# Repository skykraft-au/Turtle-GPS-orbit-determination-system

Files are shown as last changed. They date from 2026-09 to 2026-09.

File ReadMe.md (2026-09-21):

# Overview
The Turtle GPS is an open-source, cost-effective, low-power, and low-weight solution to orbit determination. The device resolves the issues faced by standard tracking methods such as radar while democratising space by making tracking cooperative and community-based. The device satisfies CoCom regulations by being post-processed and non-continuous; instead, it beacons GPS data over LoRa packets at specified intervals.

The device is highly configurable through the FPGA Verilog code; see the configuration section below for more information.

Further development on the device is needed; the community is welcome to contribute to this. Information on directions for this development can be found in the Todo section below.

## Note regarding Turtle GPS v2.0
Note that the Turtle GPS v2.0 does not work by default, as there are issues regarding the flash and power supply components on the board; these issues are resolved in version 2.1. If you wish to use version 2.0, you will need to resolve these issues. The key issues and solutions are as follows:
- There are missing pull-up resistors on pins 1, 3, and 7 of the Flash memory; these should be 10 kΩ.
- The pull-up resistors on the M0, M1, and M2 pins on the underside of the FPGA are 10 kΩ, but they should be 1 kΩ to initiate the correct startup configuration.
- A few issues exist in the lower half of the power supply, including incorrect placement of the boost converter, sensitive output of the first 3.3 V LDO, and insufficient current rating in both the diode and boost converter. To resolve this, I recommend bypassing this section by powering the board with 3.3 V through test point 3.
- The done indicator pin from the FPGA should be a pull-up and not a pull-down.

# Todo
- GPS v2.1: Resolve issues with v2.0, update FPGA clock to an LVCMOS TCXO, tune LoRa RF path to between 401 MHz and 403 MHz.
- Update code to default the LoRa frequency to 401 MHz to 403 MHz and cascade the FIR to allow for a sharper cutoff to be attained with the limited FPGA resources.
- Program LoRa receiving capabilities into the FPGA to allow for remote shutdown with a unique user-defined code.
- Optimise size, weight, and performance of the device
- Test in orbit
- Set up a public website for uploading and processing of data
- Add satellite ID code generator and logger to the website

# Configuration of the Device
By default, the packets transmitted over LoRa are 512 bits wide and include a unique, user-defined satellite ID Code, packet index, user-defined bits, and the actual data.
| Number of Bits | Bit Locations | Purpose |
| --- | --- | --- |
| 24 | \[512:489\] | Satellite ID Code |
| 12 | \[488:477\] | Packet Index |
| 28 | \[476:449\] | User-defined bits |
| 448 | \[448:0\] | GPS IQ Data |

The user-defined bits can be configured by changing the value of the respective register in the Verilog code. The configuration of the MAX2771 GNSS Receiver and the LoRa SX1276 can be changed by adjusting the values of their respective configuration registers in the MAX_Driver and LORA_Driver Verilog modules, respectively.

The total transmission size, as well as the sample size and whether samples are continuous or not, can all be configured through the value of the GPS_Config register in the GPS_Top Verilog module. Comments are included in the code to assist users with this.

# Licensing

This repository contains material under multiple licenses.

## Hardware

The hardware design files are licensed under CERN-OHL-P v2.

This includes:
- GPS v2.0/KiCad PCB/

## HDL and Software

The HDL and software source code are licensed under the MIT License.

This includes:
- GPS v2.0/Software and HDL/

## Documentation

Documentation, diagrams, and images are licensed under
Creative Commons Attribution 4.0 International (CC BY 4.0).

This includes:
- GPS v2.0/BoM/

A copy of each license is available in the licenses/ directory.

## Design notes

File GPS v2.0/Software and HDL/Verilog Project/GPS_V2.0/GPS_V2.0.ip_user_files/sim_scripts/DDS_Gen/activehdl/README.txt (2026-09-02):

################################################################################
# Vivado (TM) v2024.1 (64-bit)
#
# README.txt: Please read the sections below to understand the steps required to
#             run the exported script and how to fetch design source file details
#             from the file_info.txt file.
#
# Generated by export_simulation on Mon Aug 10 12:43:21 +1000 2026
#
################################################################################

1. Steps to run the generated simulation script

From the shell prompt in the current directory, issue the following command:-

./DDS_Gen.sh

This command will launch the 'compile', 'elaborate' and 'simulate' functions
implemented in the script file for the 3-step flow. These functions are called
from the main 'run' function in the script file.

The 'run' function first calls the 'check_args' function, the purpose of which
is to verify the generated script arguments and print error if incorrect switch
is specified. The 'run' function then calls the 'setup' function, the purpose of
which is to specify custom or initialization commands. The function also executes
following sub-functions:-
'reset_run' if -reset_run switch is specified.
'reset_log' if -reset_log switch is specified.

The purpose of 'reset_run' function' is to delete the simulator generated design
data from the previous run and the purpose of 'reset_log' function' is to delete
the simulator generated log files.

The 'run' function then calls the 'init_lib' function, the purpose of which is to
create design library mappings and directories. This function is called before the
'compile' step. By default, if '-step' switch is specified with the script then the
script will execute that specfic step, else it will execute all steps applicable
for the target simulator.

For more information on the script, please type './DDS_Gen.sh -help'

2. Design source file information

export_simulation generates a 'file_info.txt' file that contains design file information
based on the compile order when export_simulation was executed from Vivado. The file
contains information about the file name, type, library it is compiled into, whether
it is part of the IP, associated library, file path information in a comma separated
format. This file can be parsed to extract the required information for generating a
custom script or can be read from verification test infra.

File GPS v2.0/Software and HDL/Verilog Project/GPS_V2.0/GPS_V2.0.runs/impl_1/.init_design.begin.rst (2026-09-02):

<?xml version="1.0"?>
<ProcessHandle Version="1" Minor="0">
    <Process Command=".planAhead." Owner="DinoColling" Host="WINSKYK-PR7FMTG" Pid="47460">
    </Process>
</ProcessHandle>

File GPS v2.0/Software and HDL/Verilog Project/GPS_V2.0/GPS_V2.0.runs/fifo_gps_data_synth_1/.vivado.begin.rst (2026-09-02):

<?xml version="1.0"?>
<ProcessHandle Version="1" Minor="0">
    <Process Command="vivado.bat" Owner="DinoColling" Host="WINSKYK-PR7FMTG" Pid="12496" HostCore="18" HostMemory="016568107008">
    </Process>
</ProcessHandle>

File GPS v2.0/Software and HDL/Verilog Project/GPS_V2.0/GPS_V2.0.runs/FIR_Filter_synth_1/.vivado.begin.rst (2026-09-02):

<?xml version="1.0"?>
<ProcessHandle Version="1" Minor="0">
    <Process Command="vivado.bat" Owner="DinoColling" Host="WINSKYK-PR7FMTG" Pid="38172" HostCore="18" HostMemory="016568107008">
    </Process>
</ProcessHandle>

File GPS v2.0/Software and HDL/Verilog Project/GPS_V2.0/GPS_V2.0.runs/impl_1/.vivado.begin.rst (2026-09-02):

<?xml version="1.0"?>
<ProcessHandle Version="1" Minor="0">
    <Process Command="vivado.bat" Owner="DinoColling" Host="WINSKYK-PR7FMTG" Pid="2948" HostCore="18" HostMemory="016568107008">
    </Process>
</ProcessHandle>
<?xml version="1.0"?>
<ProcessHandle Version="1" Minor="0">
    <Process Command="vivado.bat" Owner="DinoColling" Host="WINSKYK-PR7FMTG" Pid="38740" HostCore="18" HostMemory="016568107008">
    </Process>
</ProcessHandle>
<?xml version="1.0"?>
<ProcessHandle Version="1" Minor="0">
    <Process Command="vivado.bat" Owner="DinoColling" Host="WINSKYK-PR7FMTG" Pid="39036" HostCore="18" HostMemory="016568107008">
    </Process>
</ProcessHandle>
<?xml version="1.0"?>
<ProcessHandle Version="1" Minor="0">
    <Process Command="vivado.bat" Owner="DinoColling" Host="WINSKYK-PR7FMTG" Pid="36636" HostCore="18" HostMemory="016568107008">
    </Process>
</ProcessHandle>
<?xml version="1.0"?>
<ProcessHandle Version="1" Minor="0">
    <Process Command="vivado.bat" Owner="DinoColling" Host="WINSKYK-PR7FMTG" Pid="20428" HostCore="18" HostMemory="016568107008">
    </Process>
</ProcessHandle>
<?xml version="1.0"?>
<ProcessHandle Version="1" Minor="0">
    <Process Command="vivado.bat" Owner="DinoColling" Host="WINSKYK-PR7FMTG" Pid="31564" HostCore="18" HostMemory="016568107008">
    </Process>
</ProcessHandle>
<?xml version="1.0"?>
<ProcessHandle Version="1" Minor="0">
    <Process Command="vivado.bat" Owner="DinoColling" Host="WINSKYK-PR7FMTG" Pid="3468" HostCore="18" HostMemory="016568107008">
    </Process>
</ProcessHandle>
<?xml version="1.0"?>
<ProcessHandle Version="1" Minor="0">
    <Process Command="vivado.bat" Owner="DinoColling" Host="WINSKYK-PR7FMTG" Pid="37884" HostCore="18" HostMemory="016568107008">
    </Process>
</ProcessHandle>
<?xml version="1.0"?>
<ProcessHandle Version="1" Minor="0">
    <Process Command="vivado.bat" Owner="DinoColling" Host="WINSKYK-PR7FMTG" Pid="37788" HostCore="18" HostMemory="016568107008">
    </Process>
</ProcessHandle>
<?xml version="1.0"?>
<ProcessHandle Version="1" Minor="0">
    <Process Command="vivado.bat" Owner="DinoColling" Host="WINSKYK-PR7FMTG" Pid="22512" HostCore="18" HostMemory="016568107008">
    </Process>
</ProcessHandle>
<?xml version="1.0"?>
<ProcessHandle Version="1" Minor="0">
    <Process Command="vivado.bat" Owner="DinoColling" Host="WINSKYK-PR7FMTG" Pid="41432" HostCore="18" HostMemory="016568107008">
    </Process>
</ProcessHandle>
<?xml version="1.0"?>
<ProcessHandle Version="1" Minor="0">
    <Process Command="vivado.bat" Owner="DinoColling" Host="WINSKYK-PR7FMTG" Pid="43732" HostCore="18" HostMemory="016568107008">
    </Process>
</ProcessHandle>
<?xml version="1.0"?>
<ProcessHandle Version="1" Minor="0">
    <Process Command="vivado.bat" Owner="DinoColling" Host="WINSKYK-PR7FMTG" Pid="5312" HostCore="18" HostMemory="016568107008">
    </Process>
</ProcessHandle>
<?xml version="1.0"?>
<ProcessHandle Version="1" Minor="0">
    <Process Command="vivado.bat" Owner="DinoColling" Host="WINSKYK-PR7FMTG" Pid="44792" HostCore="18" HostMemory="016568107008">
    </Process>
</ProcessHandle>
<?xml version="1.0"?>
<ProcessHandle Version="1" Minor="0">
    <Process Command="vivado.bat" Owner="DinoColling" Host="WINSKYK-PR7FMTG" Pid="45352" HostCore="18" HostMemory="016568107008">
    </Process>
</ProcessHandle>

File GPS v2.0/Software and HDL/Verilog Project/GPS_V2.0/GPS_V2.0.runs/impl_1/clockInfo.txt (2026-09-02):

-------------------------------------
| Tool Version : Vivado v.2024.1
| Date         : Mon Aug 24 15:19:51 2026
| Host         : WINSKYK-PR7FMTG
| Design       : design_1
| Device       : xc7s15-ftgb196-1--
-------------------------------------

For more information on clockInfo.txt clock routing debug file see https://support.xilinx.com/s/article/000035660?language=en_US

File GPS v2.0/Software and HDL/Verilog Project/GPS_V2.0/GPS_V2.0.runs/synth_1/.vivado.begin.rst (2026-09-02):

<?xml version="1.0"?>
<ProcessHandle Version="1" Minor="0">
    <Process Command="vivado.bat" Owner="DinoColling" Host="WINSKYK-PR7FMTG" Pid="12692" HostCore="18" HostMemory="016568107008">
    </Process>
</ProcessHandle>

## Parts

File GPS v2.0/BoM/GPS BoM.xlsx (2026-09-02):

Part Name | Description | Quantity | Price per Unit (AUD) (10+) | Total Price (AUD) | Link for Purchase
GRM155R60J106ME05D | 10uF Ceramic Capacitor 0402 6.3v | 8 | 0.031 | 0.248 | GRM155R60J106ME05D Murata Electronics | Ceramic Capacitors | DigiKey (https://www.digikey.com/en/products/detail/murata-electronics/GRM155R60J106ME05D/11500166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) | GRM155R60J106ME05D &10uF Ceramic Capacitor 0402 6.3v &8 &0.248 \\
GRM155R61A475MEAAD | 4.7uF Ceramic Capacitor 0402 10v | 1 | 0.092 | 0.092 | GRM155R61A475MEAAD Murata Electronics | Ceramic Capacitors | DigiKey (https://www.digikey.com.au/en/products/detail/murata-electronics/GRM155R61A475MEAAD/6234735) | GRM155R61A475MEAAD &4.7uF Ceramic Capacitor 0402 10v &1 &0.092 \\
GRM155R71H471KA01D | 470pF Ceramic Capacitor 0402 50v | 2 | 0.054 | 0.108 | GRM155R71H471KA01D Murata Electronics | Ceramic Capacitors | DigiKey (https://www.digikey.com.au/en/products/detail/murata-electronics/GRM155R71H471KA01D/587231) | GRM155R71H471KA01D &470pF Ceramic Capacitor 0402 50v &2 &0.108 \\
GRM155R71C103KA01D | 10nF Ceramic Capacitor 0402 16v | 2 | 0.031 | 0.062 | GRM155R71C103KA01D Murata Electronics | Ceramic Capacitors | DigiKey (https://www.digikey.com.au/en/products/detail/murata-electronics/GRM155R71C103KA01D/587215) | GRM155R71C103KA01D &10nF Ceramic Capacitor 0402 16v &2 &0.062 \\
GJM1555C1H1R7BB01D | 1.7pF Ceramic Capacitor 0402 50v | 1 | 0.074 | 0.074 | GJM1555C1H1R7BB01D Murata Electronics | Ceramic Capacitors | DigiKey (https://www.digikey.com.au/en/products/detail/murata-electronics/GJM1555C1H1R7BB01D/2592897) | GJM1555C1H1R7BB01D &1.7pF Ceramic Capacitor 0402 50v &1 &0.074 \\
GJM1555C1H1R1CB01D | 1.1pF Ceramic Capacitor 0402 50v | 1 | 0.052 | 0.052 | GJM1555C1H1R1CB01D Murata Electronics | Ceramic Capacitors | DigiKey (https://www.digikey.com.au/en/products/detail/murata-electronics/GJM1555C1H1R1CB01D/702277) | GJM1555C1H1R1CB01D &1.1pF Ceramic Capacitor 0402 50v &1 &0.052 \\
GRM033R60J104KE19D | 100nF Ceramic Capacitor 0201 6.3v | 27 | 0.019 | 0.513 | GRM033R60J104KE19D Murata Electronics | Ceramic Capacitors | DigiKey (https://www.digikey.com.au/en/products/detail/murata-electronics/GRM033R60J104KE19D/702433) | GRM033R60J104KE19D &100nF Ceramic Capacitor 0201 6.3v &27 &0.513 \\
GRM155R61E105KA12D | 1uF Ceramic Capacitor 0402 25v | 12 | 0.042 | 0.504 | GRM155R61E105KA12D Murata Electronics | Ceramic Capacitors | DigiKey (https://www.digikey.com.au/en/products/detail/murata-electronics/GRM155R61E105KA12D/4905139) | GRM155R61E105KA12D &1uF Ceramic Capacitor 0402 25v &12 &0.504 \\
GRM155R60J474KE19D | 0.47uF Ceramic Capacitor 0402 6.3v | 6 | 0.074 | 0.444 | GRM155R60J474KE19D Murata Electronics | Ceramic Capacitors | DigiKey (https://www.digikey.com.au/en/products/detail/murata-electronics/GRM155R60J474KE19D/702530) | GRM155R60J474KE19D &0.47uF Ceramic Capacitor 0402 6.3v &6 &0.444 \\
GCM155R71H104KE02J | 100nF Ceramic Capacitor 0402 50v | 13 | 0.05 | 0.65 | GCM155R71H104KE02J Murata Electronics | Ceramic Capacitors | DigiKey (https://www.digikey.com.au/en/products/detail/murata-electronics/GCM155R71H104KE02J/4903705) | GCM155R71H104KE02J &100nF Ceramic Capacitor 0402 50v &13 &0.65 \\
GQM1875C2E150FB12D | 15pF Ceramic Capacitor 0603 250v | 1 | 0.48 | 0.48 | GQM1875C2E150FB12D Murata Electronics | Ceramic Capacitors | DigiKey (https://www.digikey.com.au/en/products/detail/murata-electronics/GQM1875C2E150FB12D/4419970) | GQM1875C2E150FB12D &15pF Ceramic Capacitor 0603 250v &1 &0.48 \\
GCM1555C1H101JA16D | 100pF Ceramic Capacitor 0402 50v | 4 | 0.047 | 0.188 | GCM1555C1H101JA16D Murata Electronics | Ceramic Capacitors | DigiKey (https://www.digikey.com.au/en/products/detail/murata-electronics/GCM1555C1H101JA16D/4903548) | GCM1555C1H101JA16D &100pF Ceramic Capacitor 0402 50v &4 &0.188 \\
GCM1555C1H751JA16D | 750pF Ceramic Capacitor 0402 50v | 1 | 0.052 | 0.052 | GCM1555C1H751JA16D Murata Electronics | Ceramic Capacitors | DigiKey (https://www.digikey.com.au/en/products/detail/murata-electronics/GCM1555C1H751JA16D/10700551) | GCM1555C1H751JA16D &750pF Ceramic Capacitor 0402 50v &1 &0.052 \\
GRM1555C1H470JA01D | 47pF Ceramic Capacitor 0402 50v | 5 | 0.035 | 0.175 | GRM1555C1H470JA01D Murata Electronics | Ceramic Capacitors | DigiKey (https://www.digikey.com.au/en/products/detail/murata-electronics/GRM1555C1H470JA01D/3693853) | GRM1555C1H470JA01D &47pF Ceramic Capacitor 0402 50v &5 &0.175 \\
GRM155R71E473KA88D | 47nF Ceramic Capacitor 0402 25v | 3 | 0.032 | 0.096 | GRM155R71E473KA88D Murata Electronics | Ceramic Capacitors | DigiKey (https://www.digikey.com.au/en/products/detail/murata-electronics/GRM155R71E473KA88D/702519) | GRM155R71E473KA88D &47nF Ceramic Capacitor 0402 25v &3 &0.096 \\
GJM1555C1H5R6BB01D | 5.6pF Ceramic Capacitor 0402 50v | 1 | 0.074 | 0.074 | GJM1555C1H5R6BB01D Murata Electronics | Ceramic Capacitors | DigiKey (https://www.digikey.com.au/en/products/detail/murata-electronics/GJM1555C1H5R6BB01D/2593043) | GJM1555C1H5R6BB01D &5.6pF Ceramic Capacitor 0402 50v &1 &0.074 \\
GRM1555C1H4R7CA01D | 4.7pF Ceramic Capacitor 0402 50v | 1 | 0.032 | 0.032 | GRM1555C1H4R7CA01D Murata Electronics | Ceramic Capacitors | DigiKey (https://www.digikey.com.au/en/products/detail/murata-electronics/GRM1555C1H4R7CA01D/3175193) | GRM1555C1H4R7CA01D &4.7pF Ceramic Capacitor 0402 50v &1 &0.032 \\
GRM1555C1H120FA01D | 12pF Ceramic Capacitor 0402 50v | 1 | 0.073 | 0.073 | GRM1555C1H120FA01D Murata Electronics | Ceramic Capacitors | DigiKey (https://www.digikey.com.au/en/products/detail/murata-electronics/GRM1555C1H120FA01D/3693922) | GRM1555C1H120FA01D &12pF Ceramic Capacitor 0402 50v &1 &0.073 \\
GRM1555C1H8R2CA01D | 8.2pF Ceramic Capacitor 0402 50v | 1 | 0.032 | 0.032 | GRM1555C1H8R2CA01D Murata Electronics | Ceramic Capacitors | DigiKey (https://www.digikey.com.au/en/products/detail/murata-electronics/GRM1555C1H8R2CA01D/3693886) | GRM1555C1H8R2CA01D &8.2pF Ceramic Capacitor 0402 50v &1 &0.032 \\
GRM1555C1H102JA01D | 1nF Ceramic Capacitor 0402 50v | 2 | 0.05 | 0.1 | GRM1555C1H102JA01D Murata Electronics | Ceramic Capacitors | DigiKey (https://www.digikey.com.au/en/products/detail/murata-electronics/GRM1555C1H102JA01D/702509) | GRM1555C1H102JA01D &1nF Ceramic Capacitor 0402 50v &2 &0.1 \\
GJM1555C1H6R8WB01D | 6.8pF Ceramic Capacitor 0402 50v | 2 | 0.134 | 0.268 | GJM1555C1H6R8WB01D Murata Electronics | Ceramic Capacitors | DigiKey (https://www.digikey.com.au/en/products/detail/murata-electronics/GJM1555C1H6R8WB01D/6606076) | GJM1555C1H6R8WB01D &6.8pF Ceramic Capacitor 0402 50v &2 &0.268 \\
GRM32ER60G337ME05L | 330uF Ceramic Capacitor 1210 4v | 1 | 1.695 | 1.695 | GRM32ER60G337ME05L Murata Electronics | Ceramic Capacitors | DigiKey (https://www.digikey.com.au/en/products/detail/murata-electronics/GRM32ER60G337ME05L/6155746) | GRM32ER60G337ME05L &330uF Ceramic Capacitor 1210 4v &1 &1.695 \\
GRM31CR61A476ME15L | 47uF Ceramic Capacitor 1206 10v | 1 | 0.32 | 0.32 | GRM31CR61A476ME15L Murata Electronics | Ceramic Capacitors | DigiKey (https://www.digikey.com.au/en/products/detail/murata-electronics/GRM31CR61A476ME15L/2334879) | GRM31CR61A476ME15L &47uF Ceramic Capacitor 1206 10v &1 &0.32 \\
GRM1555C1H100FA01D | 10pF Ceramic Capacitor 0402 50v | 1 | 0.064 | 0.064 | GRM1555C1H100FA01D Murata Electronics | Ceramic Capacitors | DigiKey (https://www.digikey.com.au/en/products/detail/murata-electronics/GRM1555C1H100FA01D/2543854) | GRM1555C1H100FA01D &10pF Ceramic Capacitor 0402 50v &1 &0.064 \\
1210YD107MAT4A | 100uF Ceramic Capacitor 1210 16v | 8 | 2.321 | 18.568 | 1210YD107MAT4A KYOCERA AVX | Ceramic Capacitors | DigiKey (https://www.digikey.com.au/en/products/detail/kyocera-avx/1210YD107MAT4A/11211375) | 1210YD107MAT4A &100uF Ceramic Capacitor 1210 16v &8 &18.568 \\
LQW15AN5N6C10D | 5.6nH Inductor 0402 | 1 | 0.154 | 0.154 | LQW15AN5N6C10D Murata Electronics | Fixed Inductors | DigiKey (https://www.digikey.com.au/en/products/detail/murata-electronics/LQW15AN5N6C10D/2594938) | LQW15AN5N6C10D &5.6nH Inductor 0402 &1 &0.154 \\
LQW15AN8N4G8ZD | 8.4nH Inductor 0402 | 1 | 0.201 | 0.201 | LQW15AN8N4G8ZD Murata Electronics | Fixed Inductors | DigiKey (https://www.digikey.com.au/en/products/detail/murata-electronics/LQW15AN8N4G8ZD/6799020) | LQW15AN8N4G8ZD &8.4nH Inductor 0402 &1 &0.201 \\
LBR2012T220K | 22uH Inductor 0805 | 1 | 0.114 | 0.114 | LBR2012T220K Taiyo Yuden | Fixed Inductors | DigiKey (https://www.digikey.com.au/en/products/detail/taiyo-yuden/LBR2012T220K/1788938) | LBR2012T220K &22uH Inductor 0805 &1 &0.114 \\
LQW15AN56NJ00D | 56nH Inductor 0402 | 1 | 0.128 | 0.128 | LQW15AN56NJ00D Murata Electronics | Fixed Inductors | DigiKey (https://www.digikey.com.au/en/products/detail/murata-electronics/LQW15AN56NJ00D/584364) | LQW15AN56NJ00D &56nH Inductor 0402 &1 &0.128 \\
LQW15AN30NJ00D | 30nH Inductor 0402 | 1 | 0.16 | 0.16 | LQW15AN30NJ00D Murata Electronics | Fixed Inductors | DigiKey (https://www.digikey.com.au/en/products/detail/murata-electronics/LQW15AN30NJ00D/2594896) | LQW15AN30NJ00D &30nH Inductor 0402 &1 &0.16 \\
LQW15AN8N2J00D | 8.2nH Inductor 0402 | 1 | 0.128 | 0.128 | LQW15AN8N2J00D Murata Electronics | Fixed Inductors | DigiKey (https://www.digikey.com.au/en/products/detail/murata-electronics/LQW15AN8N2J00D/584353) | LQW15AN8N2J00D &8.2nH Inductor 0402 &1 &0.128 \\
LQW15AN18NG00D | 18nH Inductor 0402 | 1 | 0.14 | 0.14 | LQW15AN18NG00D Murata Electronics | Fixed Inductors | DigiKey (https://www.digikey.com.au/en/products/detail/murata-electronics/LQW15AN18NG00D/2594860) | LQW15AN18NG00D &18nH Inductor 0402 &1 &0.14 \\
LQW15AN20NJ00D | 20nH Inductor 0402 | 1 | 0.128 | 0.128 | LQW15AN20NJ00D Murata Electronics | Fixed Inductors | DigiKey (https://www.digikey.com.au/en/products/detail/murata-electronics/LQW15AN20NJ00D/2594871) | LQW15AN20NJ00D &20nH Inductor 0402 &1 &0.128 \\
RC0402FR-0720KL | 20kOhm Resistor 0402 | 1 | 0.031 | 0.031 | RC0402FR-0720KL YAGEO | Chip Resistor - Surface Mount | DigiKey (https://www.digikey.com.au/en/products/detail/yageo/RC0402FR-0720KL/726557) | RC0402FR-0720KL &20kOhm Resistor 0402 &1 &0.031 \\
RC0402FR-07220KL | 220kOhm Resistor 0402 | 1 | 0.031 | 0.031 | RC0402FR-07220KL YAGEO | Chip Resistor - Surface Mount | DigiKey (https://www.digikey.com.au/en/products/detail/yageo/RC0402FR-07220KL/726564) | RC0402FR-07220KL &220kOhm Resistor 0402 &1 &0.031 \\
RC0402FR-07100KL | 100kOhm Resistor 0402 | 4 | 0.031 | 0.124 | RC0402FR-07100KL YAGEO | Chip Resistor - Surface Mount | DigiKey (https://www.digikey.com.au/en/products/detail/yageo/RC0402FR-07100KL/726526) | RC0402FR-07100KL &100kOhm Resistor 0402 &4 &0.124 \\
RC0603FR-0710KL | 10kOhm Resistor 0402 | 16 | 0.036 | 0.576 | RC0603FR-0710KL YAGEO | Chip Resistor - Surface Mount | DigiKey (https://www.digikey.com.au/en/products/detail/yageo/RC0603FR-0710KL/726880) | RC0603FR-0710KL &10kOhm Resistor 0402 &16 &0.576 \\
RC0402JR-0733RL | 33Ohm Resistor 0402 | 25 | 0.028 | 0.7 | RC0402JR-0733RL YAGEO | Chip Resistor - Surface Mount | DigiKey (https://www.digikey.com.au/en/products/detail/yageo/RC0402JR-0733RL/726467) | RC0402JR-0733RL &33Ohm Resistor 0402 &25 &0.7 \\
RC0603FR-07330RL | 330Ohm Resistor 0402 | 3 | 0.036 | 0.108 | RC0603FR-07330RL YAGEO | Chip Resistor - Surface Mount | DigiKey (https://www.digikey.com.au/en/products/detail/yageo/RC0603FR-07330RL/727162) | RC0603FR-07330RL &330Ohm Resistor 0402 &3 &0.108 \\
RT0402BRD0715KL | 15kOhm Resistor 0402 | 1 | 0.114 | 0.114 | RT0402BRD0715KL YAGEO | Chip Resistor - Surface Mount | DigiKey (https://www.digikey.com.au/en/products/detail/yageo/RT0402BRD0715KL/1069050) | RT0402BRD0715KL &15kOhm Resistor 0402 &1 &0.114 \\
RC0402JR-070RL | 0Ohm Resistor 0402 | 2 | 0.015 | 0.03 | RC0402JR-070RL YAGEO | Chip Resistor - Surface Mount | DigiKey (https://www.digikey.com.au/en/products/detail/yageo/RC0402JR-070RL/726406) | RC0402JR-070RL &0Ohm Resistor 0402 &2 &0.03 \\
BZT52C20-7-F | 20v Zener Diode | 1 | 0.175 | 0.175 | BZT52C20-7-F Diodes Incorporated | Single Zener Diodes | DigiKey (https://www.digikey.com.au/en/products/detail/diodes-incorporated/bzt52c20-7-f/755470) | BZT52C20-7-F &20v Zener Diode &1 &0.175 \\
SML-D12U1WT86 | Red LED 0603 | 3 | 0.122 | 0.366 | SML-D12U1WT86 Rohm Semiconductor | LED Indication - Discrete | DigiKey (https://www.digikey.com.au/en/products/detail/rohm-semiconductor/sml-d12u1wt86/5843853) | SML-D12U1WT86 &Red LED 0603 &3 &0.366 \\
MT25QL128ABA1ESE-0SIT TR | Flash Memory 128Mbit | 1 | 11.521 | 11.521 | MT25QL128ABA1ESE-0SIT TR Micron Technology Inc. | Memory | DigiKey (https://www.digikey.com.au/en/products/detail/micron-technology-inc/mt25ql128aba1ese-0sit-tr/6595661) | MT25QL128ABA1ESE-0SIT TR &Flash Memory 128Mbit &1 &11.521 \\
M20-9990246 | 2 pin Connector | 1 | 0.115 | 0.115 | M20-9990246 Harwin Inc. | Headers, Male Pins | DigiKey (https://www.digikey.com.au/en/products/detail/harwin-inc/M20-9990246/3728226) | M20-9990246 &2 pin Connector &1 &0.115 \\
MMCX-J-P-H-ST-SM1 | MMCX Connector | 3 | 3.5526 | 10.6578 | MMCX-J-P-H-ST-SM1 Samtec Inc. | Coaxial Connector (RF) Assemblies | DigiKey (https://www.digikey.com.au/en/products/detail/samtec-inc/mmcx-j-p-h-st-sm1/2707983) | MMCX-J-P-H-ST-SM1 &MMCX Connector &3 &10.6578 \\
878311420 | JTAG Connector | 1 | 2.77594 | 2.77594 | 0878311420 Molex | Headers, Male Pins | DigiKey (https://www.digikey.com.au/en/products/detail/molex/0878311420/662449) | 878311420 &JTAG Connector &1 &2.77594 \\
DMP1045UQ-7 | P-Channel MOSFET | 1 | 0.47 | 0.47 | DMP1045UQ-7 Diodes Incorporated | Single FETs, MOSFETs | DigiKey (https://www.digikey.com.au/en/products/detail/diodes-incorporated/dmp1045uq-7/8537809) | DMP1045UQ-7 &P-Channel MOSFET &1 &0.47 \\
PTS647SK38SMTR2 LFS | Tactile SPST Switch | 1 | 0.374 | 0.374 | PTS647SK38SMTR2 LFS C&K | Tactile Switches | DigiKey (https://www.digikey.com.au/en/products/detail/c-k/pts647sk38smtr2-lfs/9649862) | PTS647SK38SMTR2 LFS &Tactile SPST Switch &1 &0.374 \\
ECS-TXO-2520MV-320-AN-TR | 32MHz TCXO CMOS | 1 | 2.628 | 2.628 | ECS-TXO-2520MV-320-AN-TR ECS Inc. | Oscillators | DigiKey (https://www.digikey.com.au/en/products/detail/ecs-inc/ecs-txo-2520mv-320-an-tr/13178996) | ECS-TXO-2520MV-320-AN-TR &32MHz TCXO CMOS &1 &2.628 \\
ADP160AUJZ-1.8-R7 | 1.8v LDO | 1 | 1.581 | 1.581 | ADP160AUJZ-1.8-R7 Analog Devices Inc. | Voltage Regulators - Linear, Low Drop Out (LDO) Regulators | DigiKey (https://www.digikey.com.au/en/products/detail/analog-devices-inc/adp160aujz-1-8-r7/2510619) | ADP160AUJZ-1.8-R7 &1.8v LDO &1 &1.581 \\
MAX8570ELT+T | Boost Converter | 1 | 5.772 | 5.772 | MAX8570ELT+T Analog Devices Inc./Maxim Integrated | Special Purpose Regulators | DigiKey (https://www.digikey.com.au/en/products/detail/analog-devices-inc-maxim-integrated/max8570elt-t/2658803) | MAX8570ELT+T &Boost Converter &1 &5.772 \\
LP5912-1.0DRVR | 1.0v LDO | 1 | 1.393 | 1.393 | LP5912-1.0DRVR Texas Instruments | Voltage Regulators - Linear, Low Drop Out (LDO) Regulators | DigiKey (https://www.digikey.com.au/en/products/detail/texas-instruments/LP5912-1-0DRVR/9860178) | LP5912-1.0DRVR &1.0v LDO &1 &1.393 \\
NCV4274CST33T3G | 3.3v LDO large-range | 1 | 1.197 | 1.197 | NCV4274CST33T3G onsemi | Voltage Regulators - Linear, Low Drop Out (LDO) Regulators | DigiKey (https://www.digikey.com.au/en/products/detail/onsemi/ncv4274cst33t3g/7562181) | NCV4274CST33T3G &3.3v LDO large-range &1 &1.197 \\
TLV73333PDBVR | 3.3v LDO Precise | 1 | 0.172 | 0.172 | TLV73333PDBVR Texas Instruments | Voltage Regulators - Linear, Low Drop Out (LDO) Regulators | DigiKey (https://www.digikey.com.au/en/products/detail/texas-instruments/tlv73333pdbvr/5022378) | TLV73333PDBVR &3.3v LDO Precise &1 &0.172 \\
MAX2771ETI+T | RF GNSS Receiver | 1 | 12.87104 | 12.87104 | MAX2771ETI+T Analog Devices Inc./Maxim Integrated | RF Receivers | DigiKey (https://www.digikey.com.au/en/products/detail/analog-devices-inc-maxim-integrated/max2771eti-t/9833527) | MAX2771ETI+T &RF GNSS Receiver &1 &12.87104 \\
XC7S15-1FTGB196C | Spartan-7 FPGA | 1 | 38.9 | 38.9 | XC7S15-1FTGB196C AMD | FPGAs (Field Programmable Gate Array) | DigiKey (https://www.digikey.com.au/en/products/detail/amd/xc7s15-1ftgb196c/9380262) | XC7S15-1FTGB196C &Spartan-7 FPGA &1 &38.9 \\
SX1276IMLTRT | LoRa TxRx IC | 1 | 13.312 | 13.312 | SX1276IMLTRT Semtech Corporation | RF Transceiver ICs | DigiKey (https://www.digikey.com.au/en/products/detail/semtech-corporation/sx1276imltrt/4259565) | SX1276IMLTRT &LoRa TxRx IC &1 &13.312 \\
MP06838 | 32MHz TCXO Clipped sine wave | 1 | 3.806 | 3.806 | MP06838 Golledge Electronics Ltd | Oscillators | DigiKey (https://www.digikey.com.au/en/products/detail/golledge-electronics-ltd/MP06838/16999515) | MP06838 &32MHz TCXO Clipped sine wave &1 &3.806 \\
ASWD-S2-0002-T | RF Switch | 1 | 0.368 | 0.368 | ASWD-S2-0002-T Abracon LLC | RF Switches | DigiKey (https://www.digikey.com.au/en/products/detail/abracon-llc/ASWD-S2-0002-T/26485746) | ASWD-S2-0002-T &RF Switch &1 &0.368 \\
ETXO-L33CL-100.000 | 100MHz TCXO LVDS | 1 | 20.3 | 20.3 | ETXO-L33CL-100.000 ECS Inc. | Oscillators | DigiKey (https://www.digikey.com.au/en/products/detail/ecs-inc/etxo-l33cl-100-000/18108737) | ETXO-L33CL-100.000 &100MHz TCXO LVDS &1 &20.3 \\
PCBWay PCB | PCB | 1 | 64 | 64 | China PCB Prototype & Fabrication Manufacturer - PCB Prototype the Easy Way (https://www.pcbway.com/) | PCBWay PCB &PCB &1 &64 \\
 | Parts | 192 | Total Cost (AUD) | 220.58578

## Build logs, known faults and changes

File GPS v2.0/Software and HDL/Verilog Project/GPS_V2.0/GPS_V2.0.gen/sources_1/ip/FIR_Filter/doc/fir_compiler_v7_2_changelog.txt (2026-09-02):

2024.1:
 * Version 7.2 (Rev. 22)
 * Bug Fix: Added Synplicity key
 * Other: IP packaging adjustments to address warnings from IP Packager integrity check
 * Revision change in one or more subcores

2023.2.2:
 * Version 7.2 (Rev. 21)
 * Revision change in one or more subcores

2023.2.1:
 * Version 7.2 (Rev. 20)
 * No changes

2023.2:
 * Version 7.2 (Rev. 20)
 * Bug Fix: Minor GUI fix to update Output Width range following a change in Coefficient Structure
 * Bug Fix: Update half-band interpolation "power of 2" center tap optimization to support symmetric rounding
 * Other: Rebrand to AMD copyright information
 * Revision change in one or more subcores

2023.1.2:
 * Version 7.2 (Rev. 19)
 * No changes

2023.1.1:
 * Version 7.2 (Rev. 19)
 * No changes

2023.1:
 * Version 7.2 (Rev. 19)
 * General: Device support changes. No change to functionality or performance

2022.2.2:
 * Version 7.2 (Rev. 18)
 * No changes

2022.2.1:
 * Version 7.2 (Rev. 18)
 * No changes

2022.2:
 * Version 7.2 (Rev. 18)
 * No changes

2022.1.2:
 * Version 7.2 (Rev. 18)
 * No changes

2022.1.1:
 * Version 7.2 (Rev. 18)
 * No changes

2022.1:
 * Version 7.2 (Rev. 18)
 * Feature Enhancement: C model MEX wrapper updates to support Octave

2021.2.2:
 * Version 7.2 (Rev. 17)
 * No changes

2021.2.1:
 * Version 7.2 (Rev. 17)
 * No changes

2021.2:
 * Version 7.2 (Rev. 17)
 * Bug Fix: Fixed convergent rounding bug for symmetric polyphase decimators

2021.1.1:
 * Version 7.2 (Rev. 16)
 * No changes

2021.1:
 * Version 7.2 (Rev. 16)
 * Bug Fix: Fixed width mismatch issue with SSR single rate extended multiply reload configs
 * Other: testbench and constraints updates

2020.3:
 * Version 7.2 (Rev. 15)
 * No changes

2020.2.2:
 * Version 7.2 (Rev. 15)
 * No changes

2020.2.1:
 * Version 7.2 (Rev. 15)
 * No changes

2020.2:
 * Version 7.2 (Rev. 15)
 * Bug Fix: Fixed incorrect application of symmetry when Interpolation_Rate > clk_freq/samp_freq > 1
 * Feature Enhancement: Improved GUI error reporting for designs that don't fit within selected device.
 * Other: Windows C model compilation now uses Visual Studio 2017

2020.1.1:
 * Version 7.2 (Rev. 14)
 * No changes

2020.1:
 * Version 7.2 (Rev. 14)
 * Bug Fix: Fixed bug with coefficient reload file.
 * Bug Fix: Improved error trapping behaviour in the GUI.
 * Bug Fix: Fixed simulator specific bug
 * Feature Enhancement: Extended Symmetric Coefficient Structures for Interpolation and Decimation Filters with Super Sample Rate.
 * Feature Enhancement: Improved the GUI for selecting optimizations.

2019.2.2:
 * Version 7.2 (Rev. 13)
 * No changes

2019.2.1:
 * Version 7.2 (Rev. 13)
 * No changes

2019.2:
 * Version 7.2 (Rev. 13)
 * General: Improved efficiency to C model output. No change to functionality.

2019.1.3:
 * Version 7.2 (Rev. 12)
 * No changes

2019.1.2:
 * Version 7.2 (Rev. 12)
 * No changes

2019.1.1:
 * Version 7.2 (Rev. 12)
 * No changes

2019.1:
 * Version 7.2 (Rev. 12)
 * Bug Fix: Addressing memory leak in MEX wrapper.
 * Bug Fix: Fixed coefficient width range minimum for coefficient file input.
 * Bug Fix: Fixed upper bound of Sample Frequency when Advanced Channel Sequence is selected.
 * Bug Fix: Fixed C model crash when multiple DSP IP C models are run together: AR 71876
 * Other: Support for new devices. No change to exisiting functionality, resource use or performance.
 * Revision change in one or more subcores

2018.3.1:
 * Version 7.2 (Rev. 11)
 * No changes

2018.3:
 * Version 7.2 (Rev. 11)
 * No changes

2018.2:
 * Version 7.2 (Rev. 11)
 * No changes

2018.1:
 * Version 7.2 (Rev. 11)
 * Revision change in one or more subcores

2017.4:
 * Version 7.2 (Rev. 10)
 * Feature Enhancement: Add option to remove shift register inference attributes; SHREG_EXTRACT and SRL_STYLE

2017.3:
 * Version 7.2 (Rev. 9)
 * Feature Enhancement: Increase the maximum number of parallel inputs from 64 to 256
 * Revision change in one or more subcores

2017.2:
 * Version 7.2 (Rev. 8)
 * No changes

2017.1:
 * Version 7.2 (Rev. 8)
 * Bug Fix: Output Rounding Mode parameter validation corrected to produce an error during design validation (IP Integrator/System Generator) rather than silently updating to a legal value.
 * Bug Fix: Correction to Convergent Rounding when multiple DSP slices are required to implement the filter multiply operations.

2016.4:
 * Version 7.2 (Rev. 7)
 * No changes

2016.3:
 * Version 7.2 (Rev. 7)
 * General: Support for Spartan7 devices
 * Revision change in one or more subcores

2016.2:
 * Version 7.2 (Rev. 6)
 * No changes

2016.1:
 * Version 7.2 (Rev. 6)
 * Fix for error in Sysgen parameter propagation.
 * Enabled DSP48 ADREG/DREG but gate CEAD/CED to address power DRC.
 * Fix in common c model utilities package for handling of arrays of real types in Matlab
 * Revision change in one or more subcores

2015.4.2:
 * Version 7.2 (Rev. 5)
 * No changes

2015.4.1:
 * Version 7.2 (Rev. 5)
 * No changes

2015.4:
 * Version 7.2 (Rev. 5)
 * Correction to GUI reported Calculated Coefficients for Transpose Interpolation filters.
 * Revision change in one or more subcores

2015.3:
 * Version 7.2 (Rev. 4)
 * Add constraints file to suppress expected memory collision warnings during post-synthesis simulation.
 * IP revision number added to HDL module, library, and include file names, to support designs with both locked and upgraded IP instances
 * Correction to GUI reported latency estimate for polyphase interpolation configurations.
 * Revision change in one or more subcores

2015.2.1:
 * Version 7.2 (Rev. 3)
 * No changes

2015.2:
 * Version 7.2 (Rev. 3)
 * Correction to the GUI reported startup latency for polyphase interpolation configurations.
 * Correction for Halfband Decimation with Symmetric rounding on Ultrascale parts.
 * Correction for Polyphase Interpolation with Convergent rounding where multiple DSP columns are required to support the data and/or coefficient width.

2015.1:
 * Version 7.2 (Rev. 2)
 * Warning reduction.
 * Correction to single rate half-band control for data vector reset, an oversample rate of 2, utilizing a single multiply add unit.
 * Added the SRL_STYLE attribute to the delay component to ensure an efficient implementation.
 * Fix to Sample Period propagation to avoid false Column Configuration errors.
 * GUI filter coefficient processing speed up for bit widths greater than DSP48 input width.
 * Addition of Beta support for future devices
 * Correction to fractional interpolation configurations utilizing Maximium Possible hardware oversampling specification in System Generator.
 * Update to C model to match GUI behaviour. Add support for quantization/truncation of integer only coefficients when XIP_FIR_QUANTIZED_ONLY has been specified.
 * Supported devices and production status are now determined automatically, to simplify support for future devices
 * C models are no longer provided for 32-bit operating systems as Vivado has deprecated 32-bit OS support

2014.4.1:
 * Version 7.2 (Rev. 1)
 * No changes

2014.4:
 * Version 7.2 (Rev. 1)
 * Fix for UltraScale Halfband Interpolation optimization with Convergent Rounding and multiple parallel paths.
 * C Model maximum data and coefficient widths updated for UltraScale.
 * Correction to GUI latency calculation.
 * Encrypted source files are concatenated together to reduce the number of files and to reduce simulator compile time
 * Add 1 x fs Advanced Channel Sequence to sequence length 24.
 * Enabled out-of-context clock frequency setting by adding FREQ_HZ parameter to clock interface aclk_intf

2014.3:
 * Version 7.2
 * Optimized Halfband filter support for UltraScale devices.
 * Super sample rate support.
 * Enhanced Hardware Oversampling specification methods. Now supports input and output sample period specification.
 * CONFIG channel behavior has been updated for the Packet Synchronization method (On Packet) following power up or reset.

2014.2:
 * Version 7.1 (Rev. 4)
 * Removed component statement for DSP48E2, no functional changes

2014.1:
 * Version 7.1 (Rev. 3)
 * C models for Windows are compiled using Microsoft Visual Studio 2012
 * Internal device family name change, no functional changes
 * Netlists created by write_verilog and write_vhdl are IEEE P1735 encrypted, with keys for supported simulators so that netlist simulation can still be done
 * Enable third party synthesis tools to read encrypted netlists (but not source HDL)
 * Fixed AR58946, COE file coefficient specification now working correctly in IP Integrator.
 * Support for Virtex Ultrascale devices at Pre-Production Status

2013.4:
 * Version 7.1 (Rev. 2)
 * Added workaround to the GUI for AR57785
 * Support for Kintex Ultrascale devices at Pre-Production Status

2013.3:
 * Version 7.1 (Rev. 1)
 * Behavioral VHDL model replaced by Encrypted RTL. For more information on this change please refer to the Migrating and Upgrading section in the Product Guide
 * Internal standardization in source file delivery, does not change behavior
 * Support for Automotive Artix-7, Automotive Zynq, Defense Grade Artix-7, Defense Grade Zynq and Lower Power Artix-7 devices at Production Status
 * Added default constraints for out of context flow
 * Optimized support for UltraScale devices
 * Added support for Cadence IES and Synopsys VCS simulators
 * Removed C model dependency on stlport (STL Portability) library; C model now uses STL built into the compiler
 * Windows C model DLLs are statically linked to the Windows C run-time (CRT) library, to remove the runtime dependency on MSVCRT90.dll, which can cause problems when using the C model in a Windows compiler other than Visual Studio 2008
 * C model updated to use third-party library MPIR version 2.6.0 (previously was version 2.2.1); the Windows MPIR DLLs are also statically linked to the Windows CRT library, to remove the dependency on MSVCRT90.dll

2013.2:
 * Version 7.1
 * Support for Series 7 devices at Production status
 * Beta support for future devices
 * Enhanced Optimization specification including optional use of Block RAM READ-FIRST mode
 * Maximum interleaved channels increased to 1024
 * Bug Fixes

2013.1:
 * Version 7.0
 * Native Vivado Release
 * There have been no functional or interface changes to this IP.  The version number has changed to support unique versioning in Vivado starting with 2013.1.

(c) Copyright 2002 - 2024 Advanced Micro Devices, Inc. All rights reserved.

This file contains confidential and proprietary information
of AMD and is protected under U.S. and international copyright
and other intellectual property laws.

DISCLAIMER
This disclaimer is not a license and does not grant any
rights to the materials distributed herewith. Except as
otherwise provided in a valid license issued to you by
AMD, and to the maximum extent permitted by applicable
law: (1) THESE MATERIALS ARE MADE AVAILABLE "AS IS" AND
WITH ALL FAULTS, AND AMD HEREBY DISCLAIMS ALL WARRANTIES
AND CONDITIONS, EXPRESS, IMPLIED, OR STATUTORY, INCLUDING
BUT NOT LIMITED TO WARRANTIES OF MERCHANTABILITY, NON-
INFRINGEMENT, OR FITNESS FOR ANY PARTICULAR PURPOSE; and
(2) AMD shall not be liable (whether in contract or tort,
including negligence, or under any other theory of
liability) for any loss or damage of any kind or nature
related to, arising under or in connection with these
materials, including for any direct, or any indirect,
special, incidental, or consequential loss or damage
(including loss of data, profits, goodwill, or any type of
loss or damage suffered as a result of any action brought
by a third party) even if such damage or loss was
reasonably foreseeable or AMD had been advised of the
possibility of the same.

CRITICAL APPLICATIONS
AMD products are not designed or intended to be fail-
safe, or for use in any application requiring fail-safe
performance, such as life-support or safety devices or
systems, Class III medical devices, nuclear facilities,
applications related to the deployment of airbags, or any
other applications that could lead to death, personal
injury, or severe property or environmental damage
(individually and collectively, "Critical
Applications"). Customer assumes the sole risk and
liability of any use of AMD products in Critical
Applications, subject only to applicable laws and
regulations governing limitations on product liability.

THIS COPYRIGHT NOTICE AND DISCLAIMER MUST BE RETAINED AS
PART OF THIS FILE AT ALL TIMES.

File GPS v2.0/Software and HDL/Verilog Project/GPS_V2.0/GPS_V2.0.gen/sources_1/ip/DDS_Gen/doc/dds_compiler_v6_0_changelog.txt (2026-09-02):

2024.1:
 * Version 6.0 (Rev. 25)
 * General: IP packaging adjustments to address warnings from IP Packager integrity check
 * General: Float support for sin/cos generation of the DDS core
 * Revision change in one or more subcores

2023.2.2:
 * Version 6.0 (Rev. 24)
 * Revision change in one or more subcores

2023.2.1:
 * Version 6.0 (Rev. 23)
 * No changes

2023.2:
 * Version 6.0 (Rev. 23)
 * General: Rebrand to AMD copyright information
 * Revision change in one or more subcores

2023.1.2:
 * Version 6.0 (Rev. 22)
 * No changes

2023.1.1:
 * Version 6.0 (Rev. 22)
 * No changes

2023.1:
 * Version 6.0 (Rev. 22)
 * No changes

2022.2.2:
 * Version 6.0 (Rev. 22)
 * No changes

2022.2.1:
 * Version 6.0 (Rev. 22)
 * No changes

2022.2:
 * Version 6.0 (Rev. 22)
 * No changes

2022.1.2:
 * Version 6.0 (Rev. 22)
 * No changes

2022.1.1:
 * Version 6.0 (Rev. 22)
 * No changes

2022.1:
 * Version 6.0 (Rev. 22)
 * General: Matlab demonstration smoke test updated to suit internal test. No change to functionality or performance.
 * Revision change in one or more subcores

2021.2.2:
 * Version 6.0 (Rev. 21)
 * No changes

2021.2.1:
 * Version 6.0 (Rev. 21)
 * No changes

2021.2:
 * Version 6.0 (Rev. 21)
 * No changes

2021.1.1:
 * Version 6.0 (Rev. 21)
 * No changes

2021.1:
 * Version 6.0 (Rev. 21)
 * Revision change in one or more subcores

2020.3:
 * Version 6.0 (Rev. 20)
 * No changes

2020.2.2:
 * Version 6.0 (Rev. 20)
 * No changes

2020.2.1:
 * Version 6.0 (Rev. 20)
 * No changes

2020.2:
 * Version 6.0 (Rev. 20)
 * No changes

2020.1.1:
 * Version 6.0 (Rev. 20)
 * No changes

2020.1:
 * Version 6.0 (Rev. 20)
 * General: Enabling hexadecimal input on GUI

2019.2.2:
 * Version 6.0 (Rev. 19)
 * No changes

2019.2.1:
 * Version 6.0 (Rev. 19)
 * No changes

2019.2:
 * Version 6.0 (Rev. 19)
 * Revision change in one or more subcores

2019.1.3:
 * Version 6.0 (Rev. 18)
 * No changes

2019.1.2:
 * Version 6.0 (Rev. 18)
 * No changes

2019.1.1:
 * Version 6.0 (Rev. 18)
 * No changes

2019.1:
 * Version 6.0 (Rev. 18)
 * Bug Fix: Addressing memory leak in MEX wrapper.
 * Bug Fix: Fixed C model crash when multiple DSP IP C models are run together: AR 71876
 * Revision change in one or more subcores

2018.3.1:
 * Version 6.0 (Rev. 17)
 * No changes

2018.3:
 * Version 6.0 (Rev. 17)
 * General: Support for new devices. No change to functionality.

2018.2:
 * Version 6.0 (Rev. 16)
 * No changes

2018.1:
 * Version 6.0 (Rev. 16)
 * General: Add cstring include to run_bitacc_cmodel.c to allow correct compilation with some later versions of GCC. No change to functionality.
 * General: Disable unnecessary C model debug output when dithering enable. No change to functionality.
 * Revision change in one or more subcores

2017.4:
 * Version 6.0 (Rev. 15)
 * General: Add cstdlib include to run_bitacc_cmodel to allow correct compilation with later versions of GCC. No change to functionality.

2017.3:
 * Version 6.0 (Rev. 14)
 * General: Comment change in C model. No change to functionality
 * Revision change in one or more subcores

2017.2:
 * Version 6.0 (Rev. 13)
 * No changes

2017.1:
 * Version 6.0 (Rev. 13)
 * No changes

2016.4:
 * Version 6.0 (Rev. 13)
 * No changes

2016.3:
 * Version 6.0 (Rev. 13)
 * General: Support for Spartan7 devices
 * Revision change in one or more subcores

2016.2:
 * Version 6.0 (Rev. 12)
 * No changes

2016.1:
 * Version 6.0 (Rev. 12)
 * Fix in common c model utilities package for handling of arrays of real types in Matlab
 * Revision change in one or more subcores

2015.4.2:
 * Version 6.0 (Rev. 11)
 * No changes

2015.4.1:
 * Version 6.0 (Rev. 11)
 * No changes

2015.4:
 * Version 6.0 (Rev. 11)
 * Revision change in one or more subcores

2015.3:
 * Version 6.0 (Rev. 10)
 * IP revision number added to HDL module, library, and include file names, to support designs with both locked and upgraded IP instances
 * GUI PINC calculation when using System parameters in Rasterized Mode corrected
 * Revision change in one or more subcores

2015.2.1:
 * Version 6.0 (Rev. 9)
 * No changes

2015.2:
 * Version 6.0 (Rev. 9)
 * Addition of MEX wrapper

2015.1:
 * Version 6.0 (Rev. 8)
 * C model updated to increase maximum Frequency Resolution from 10kHz to 125MHz.
 * Performance improved for cases above SFDR of 120dB or output width 20bits.
 * C model bugfix for situation where accumulator width could differ by 1 bit from that used by the IP core.
 * Addition of Beta support for future devices
 * Additional parameter checking added to C model
 * Supported devices and production status are now determined automatically, to simplify support for future devices
 * GUI behaviour changed so that Phase_Out appears by default when both phase_generator and sin_cos lut are selected
 * GUI changed to add explicit error message for out-of-range System clock.
 * C models are no longer provided for 32-bit operating systems as Vivado has deprecated 32-bit OS support

2014.4.1:
 * Version 6.0 (Rev. 7)
 * No changes

2014.4:
 * Version 6.0 (Rev. 7)
 * Encrypted source files are concatenated together to reduce the number of files and to reduce simulator compile time
 * Enabled out-of-context clock frequency setting by adding FREQ_HZ parameter to clock interface aclk_intf

2014.3:
 * Version 6.0 (Rev. 6)
 * DDS_Clock_Rate maximum value limit relaxed to 1000MHz. The actual maximum achievable will be determined by configuration and device.
 * C model smoke test run_bitacc_cmodel.c updated to correctly print negative values for sine and cosine when debug is enabled.  Also removed "using namespace std" line and replaced with "std::" where necessary.

2014.2:
 * Version 6.0 (Rev. 5)
 * DDS_Clock_Rate maximum value of 550MHz may restrict designs on new, fast devices. Setting Parameter Entry to Hardware_parameters can be used to work around the restriction.

2014.1:
 * Version 6.0 (Rev. 4)
 * sin_cos.vhd and sin_cos_quad_rast.vhd changed to work around simulation warnings. This change does not affect the behavior or performance of the core.
 * C models for Windows are compiled using Microsoft Visual Studio 2012
 * Internal device family name change, no functional changes
 * Netlists created by write_verilog and write_vhdl are IEEE P1735 encrypted, with keys for supported simulators so that netlist simulation can still be done
 * Enable third party synthesis tools to read encrypted netlists (but not source HDL)
 * Support for Virtex Ultrascale devices at Pre-Production Status

2013.4:
 * Version 6.0 (Rev. 3)
 * Fixed issue in GUI regarding illegal Phase_Angle_Values when Rasterized Mode_of_Operation was selected.
 * Missing GUI tooltips added.
 * GUI dependency between DSP48_Use and Latency corrected.
 * Support for Kintex Ultrascale devices at Pre-Production Status

2013.3:
 * Version 6.0 (Rev. 2)
 * Cosmetic GUI changes to table header row, no change in functionality
 * Fixed issue where the behavior of 2-channel rasterized configurations produced incorrect outputs; see Xilinx Answer 56597.
 * Fixed issue of incorrect sign extension of M_AXIS_PHASE_TDATA for Rasterized configurations.
 * Behavioral VHDL model replaced by Encrypted RTL. For more information on this change please refer to the Migrating and Upgrading section in the Product Guide
 * Fixed issue of C model crash when calling reset function with configurations without a phase generator.
 * Internal standardization in source file delivery, does not change behavior
 * Support for Automotive Artix-7, Automotive Zynq, Defense Grade Artix-7, Defense Grade Zynq and Lower Power Artix-7 devices at Production Status
 * Added default constraints for out of context flow
 * Added support for Cadence IES and Synopsys VCS simulators
 * Removed C model dependency on stlport (STL Portability) library; C model now uses STL built into the compiler
 * Windows C model DLLs are statically linked to the Windows C run-time (CRT) library, to remove the runtime dependency on MSVCRT90.dll, which can cause problems when using the C model in a Windows compiler other than Visual Studio 2008

2013.2:
 * Version 6.0 (Rev. 1)
 * Support for Series 7 devices at Production status
 * Repackaged IP to remove internal debug ports from GUI symbol
 * Beta support for future devices
 * Removing support for Defense Grade Low Power Artix7

2013.1:
 * Version 6.0
 * Native Vivado Release
 * Added support for Zynq
 * Added C model
 * Added Rasterized Mode of Operation feature
 * Added Resync Feature
 * Added Output Form Feature
 * Fixed issue of AR42351. The TLAST signal in 2-channel configurations could initialize to the wrong value.
 * Fixed issue of AR40551. The first cycle following the de-assertion of ARESETn could previously be ignored.
 * Fixed issue where the S_AXIS_CONFIG channel could reach a lock-up state in certain mark-space patterns of ACLKEN.
 * Fixed issue of AR51915. The demonstration testbench could give syntax errors in certain configurations.

(c) Copyright 2006 - 2024 Advanced Micro Devices, Inc. All rights reserved.

This file contains confidential and proprietary information
of AMD and is protected under U.S. and international copyright
and other intellectual property laws.

DISCLAIMER
This disclaimer is not a license and does not grant any
rights to the materials distributed herewith. Except as
otherwise provided in a valid license issued to you by
AMD, and to the maximum extent permitted by applicable
law: (1) THESE MATERIALS ARE MADE AVAILABLE "AS IS" AND
WITH ALL FAULTS, AND AMD HEREBY DISCLAIMS ALL WARRANTIES
AND CONDITIONS, EXPRESS, IMPLIED, OR STATUTORY, INCLUDING
BUT NOT LIMITED TO WARRANTIES OF MERCHANTABILITY, NON-
INFRINGEMENT, OR FITNESS FOR ANY PARTICULAR PURPOSE; and
(2) AMD shall not be liable (whether in contract or tort,
including negligence, or under any other theory of
liability) for any loss or damage of any kind or nature
related to, arising under or in connection with these
materials, including for any direct, or any indirect,
special, incidental, or consequential loss or damage
(including loss of data, profits, goodwill, or any type of
loss or damage suffered as a result of any action brought
by a third party) even if such damage or loss was
reasonably foreseeable or AMD had been advised of the
possibility of the same.

CRITICAL APPLICATIONS
AMD products are not designed or intended to be fail-
safe, or for use in any application requiring fail-safe
performance, such as life-support or safety devices or
systems, Class III medical devices, nuclear facilities,
applications related to the deployment of airbags, or any
other applications that could lead to death, personal
injury, or severe property or environmental damage
(individually and collectively, "Critical
Applications"). Customer assumes the sole risk and
liability of any use of AMD products in Critical
Applications, subject only to applicable laws and
regulations governing limitations on product liability.

THIS COPYRIGHT NOTICE AND DISCLAIMER MUST BE RETAINED AS
PART OF THIS FILE AT ALL TIMES.

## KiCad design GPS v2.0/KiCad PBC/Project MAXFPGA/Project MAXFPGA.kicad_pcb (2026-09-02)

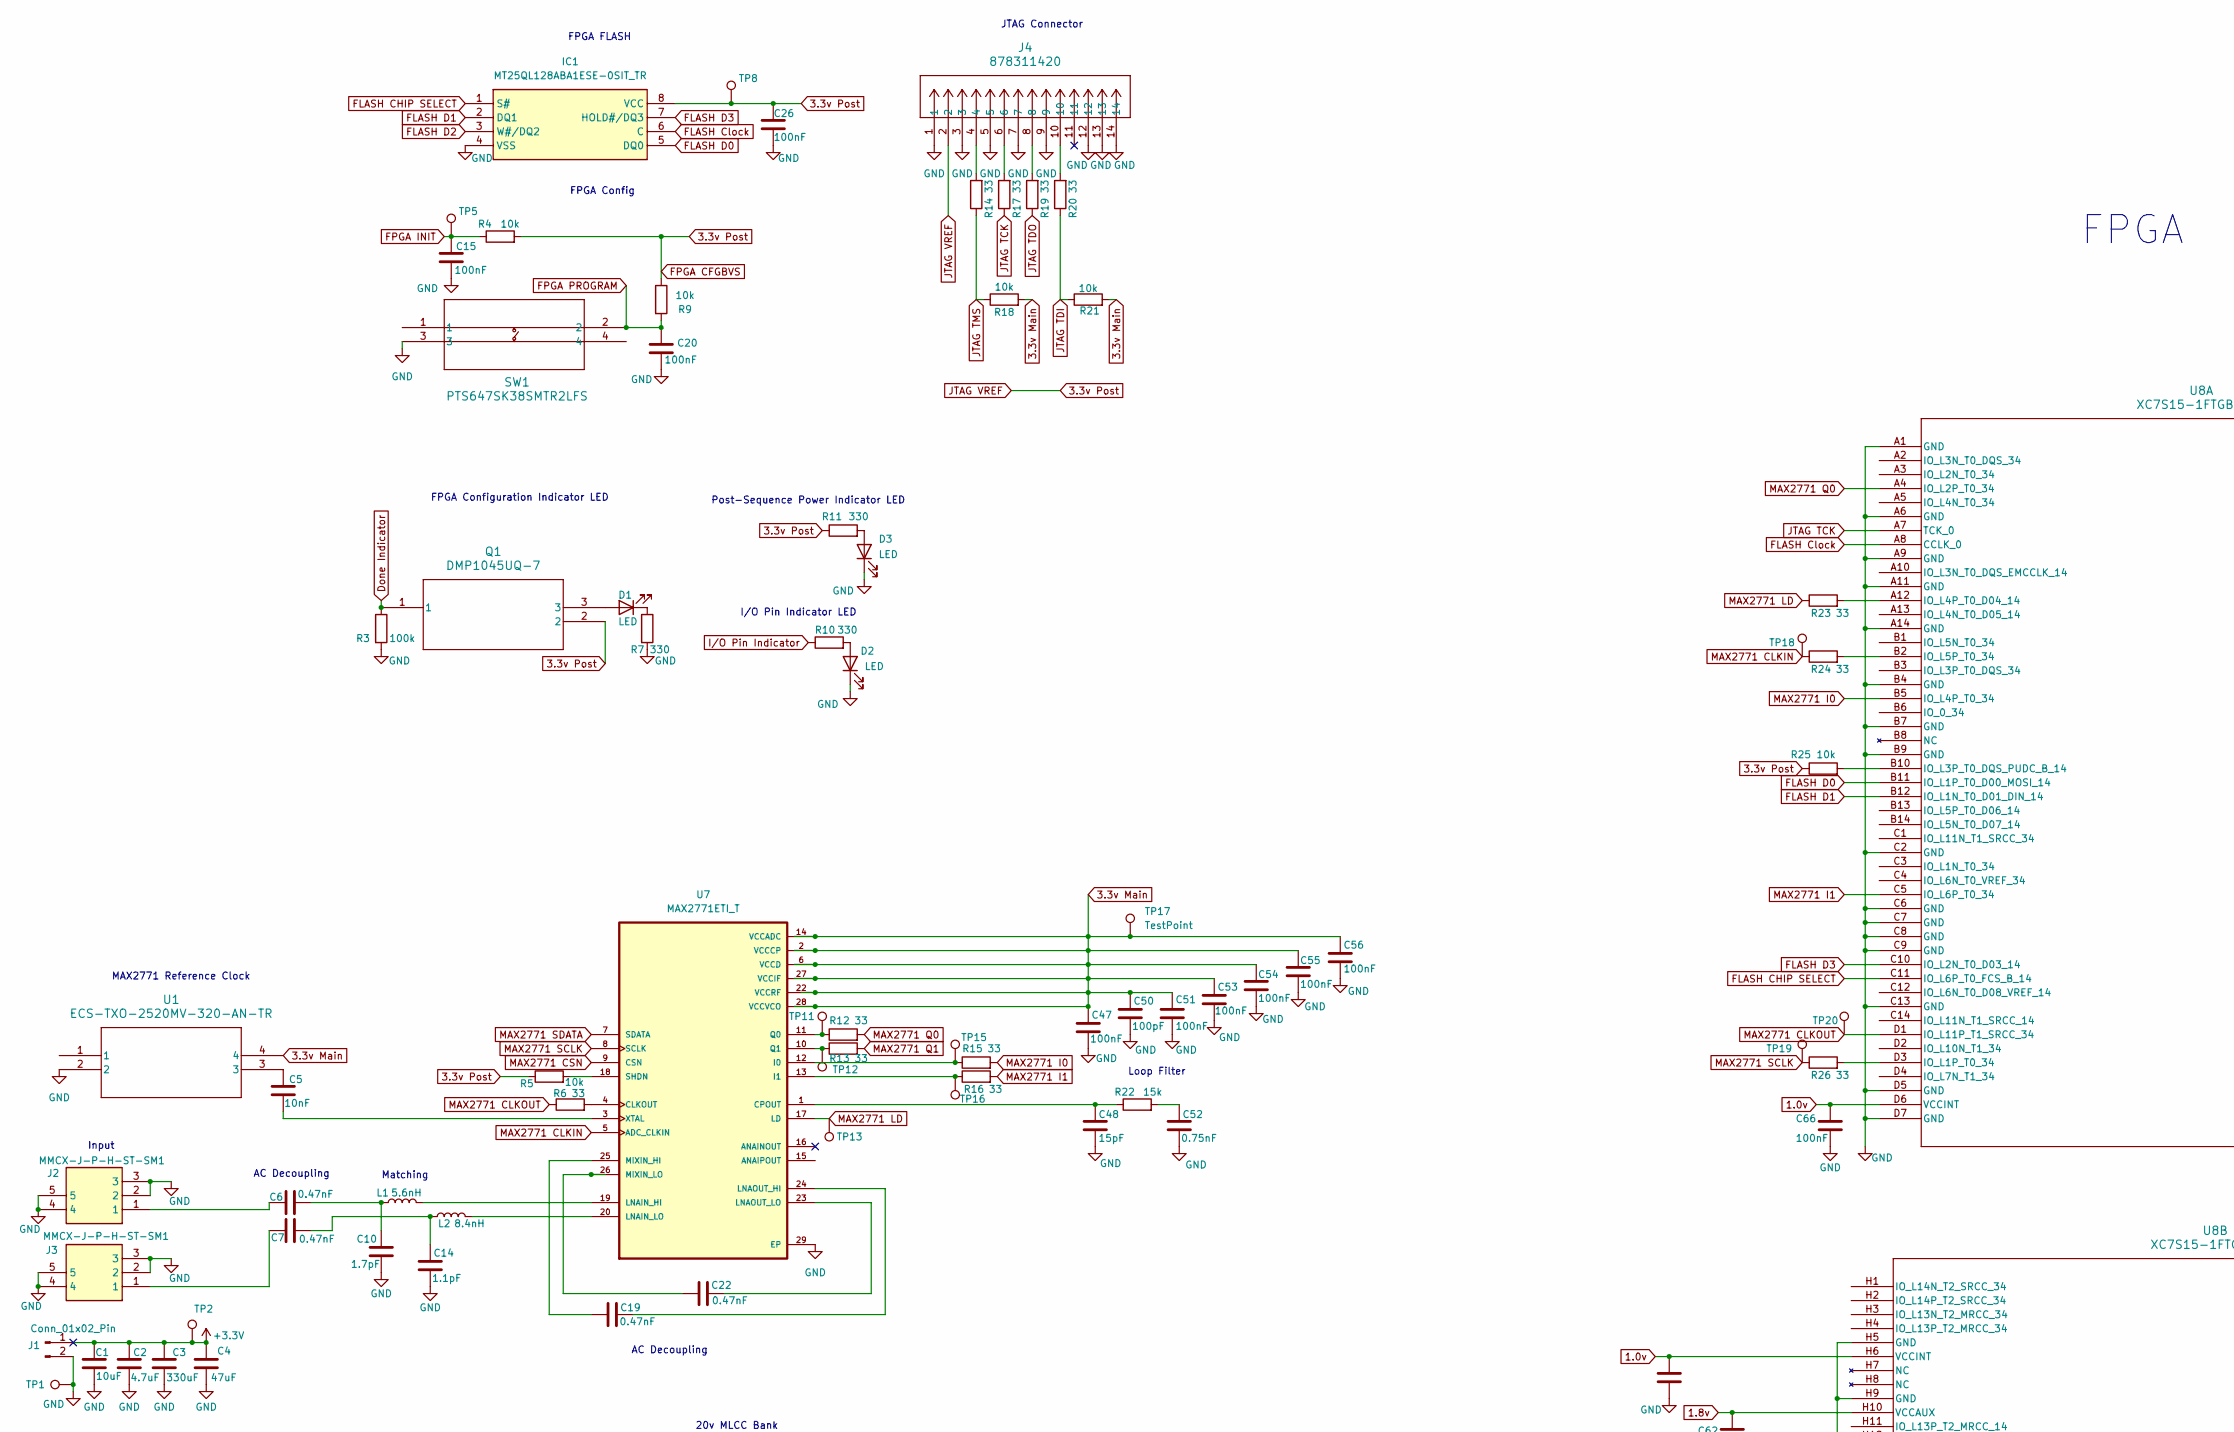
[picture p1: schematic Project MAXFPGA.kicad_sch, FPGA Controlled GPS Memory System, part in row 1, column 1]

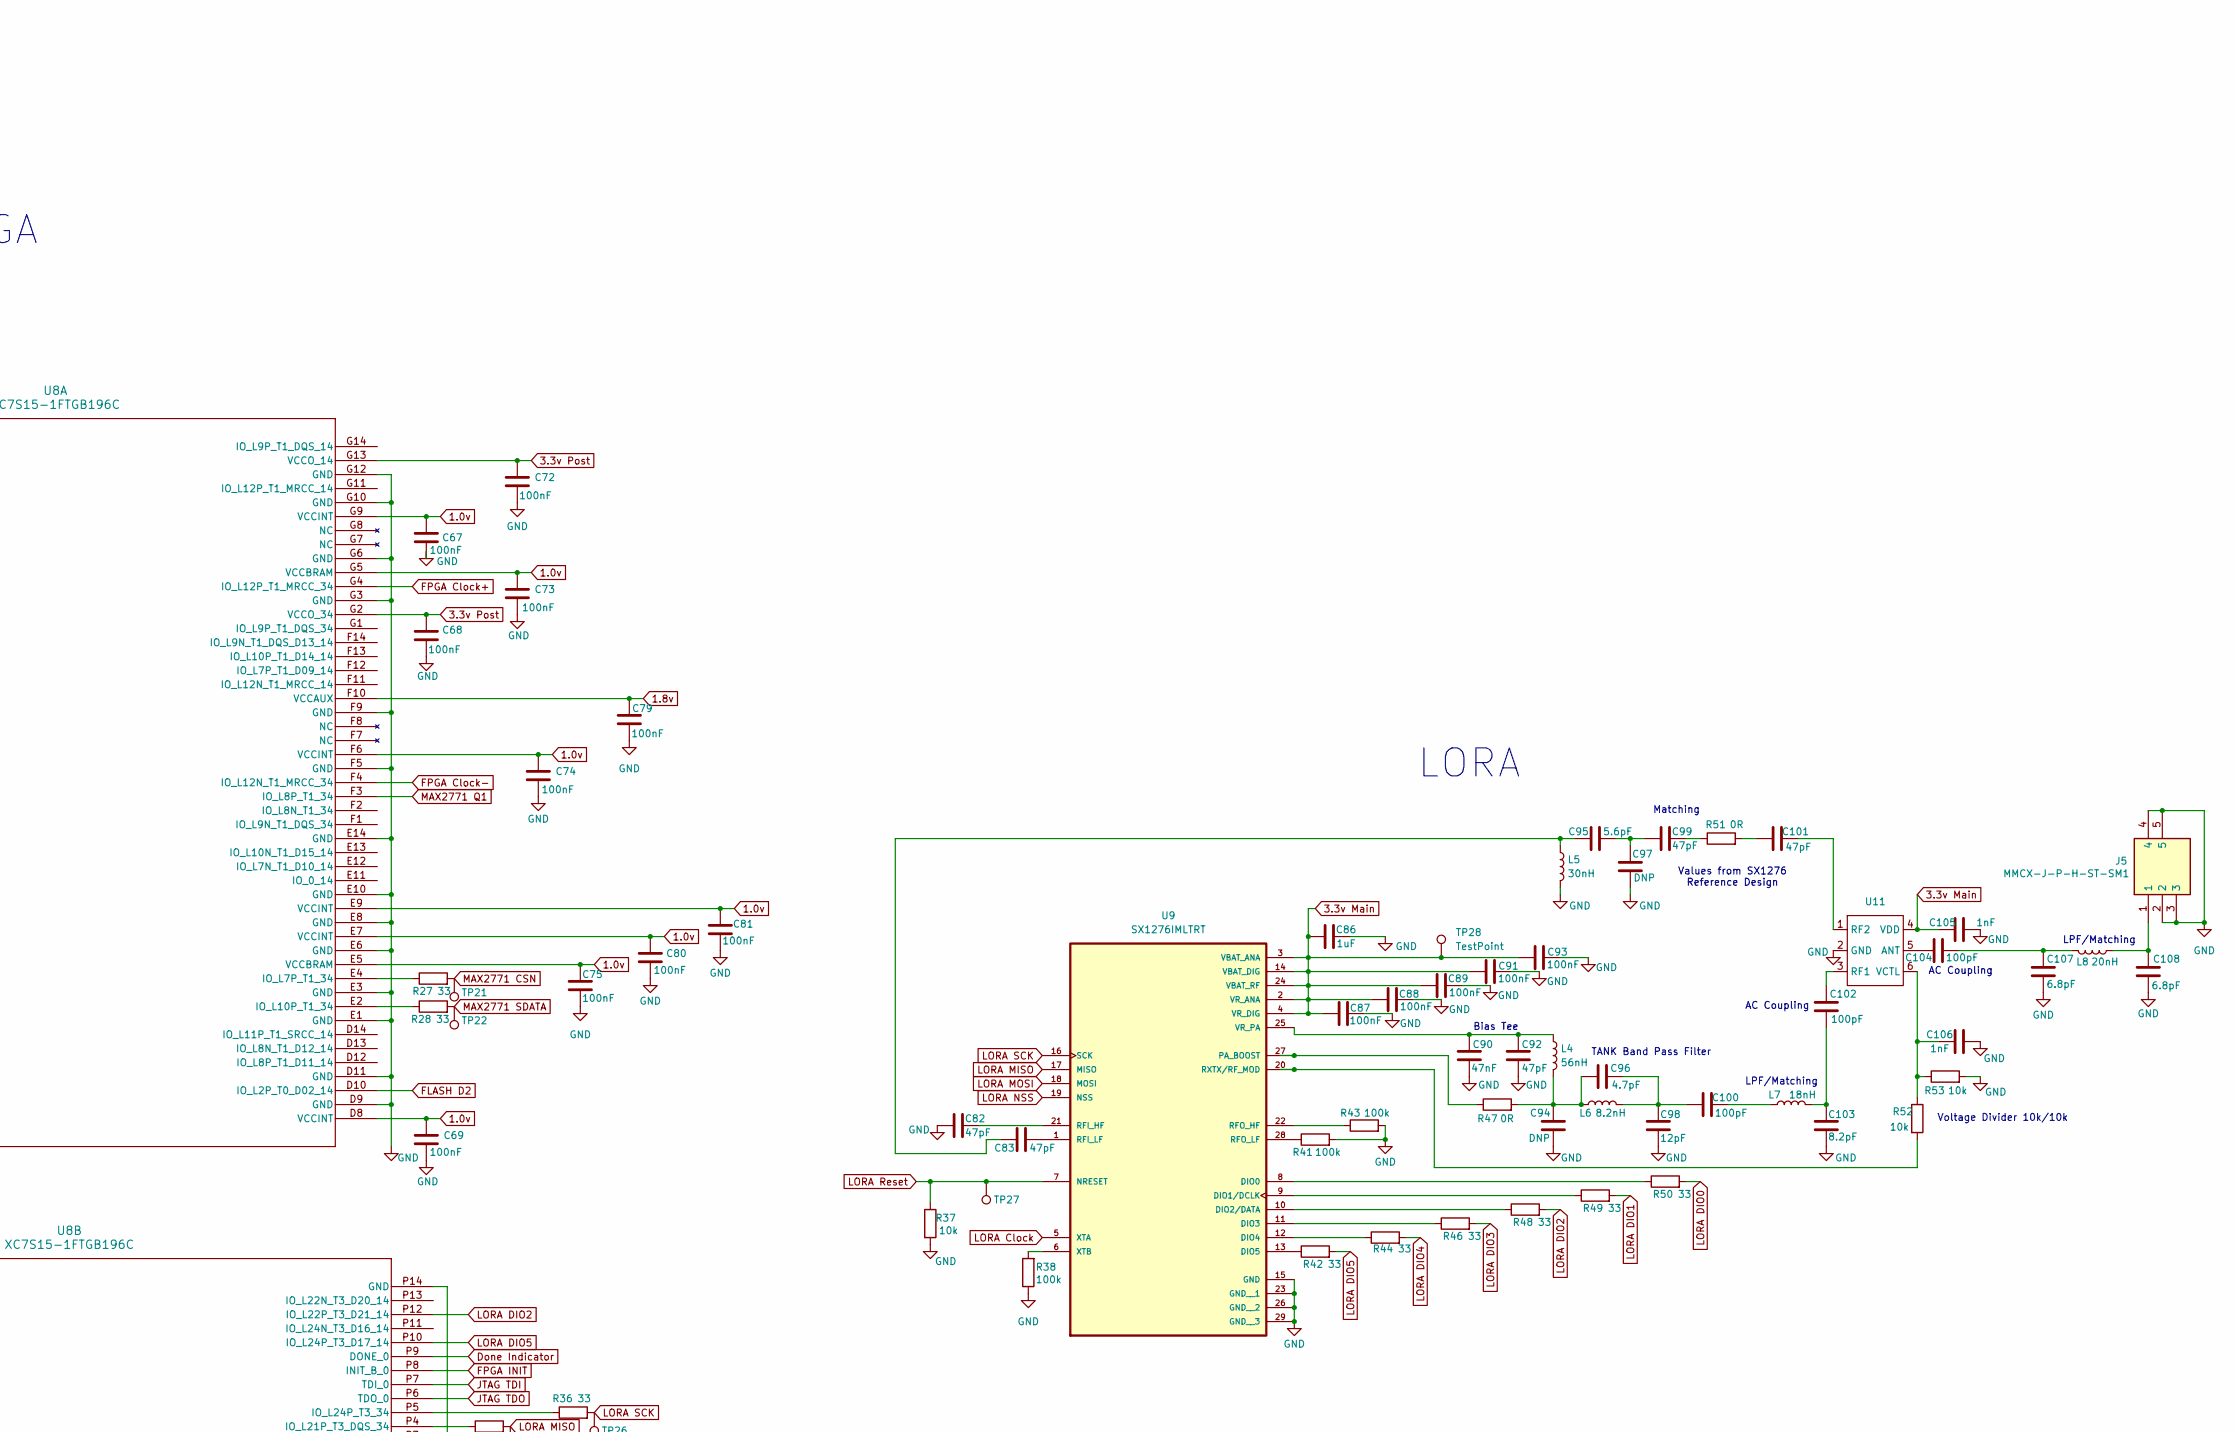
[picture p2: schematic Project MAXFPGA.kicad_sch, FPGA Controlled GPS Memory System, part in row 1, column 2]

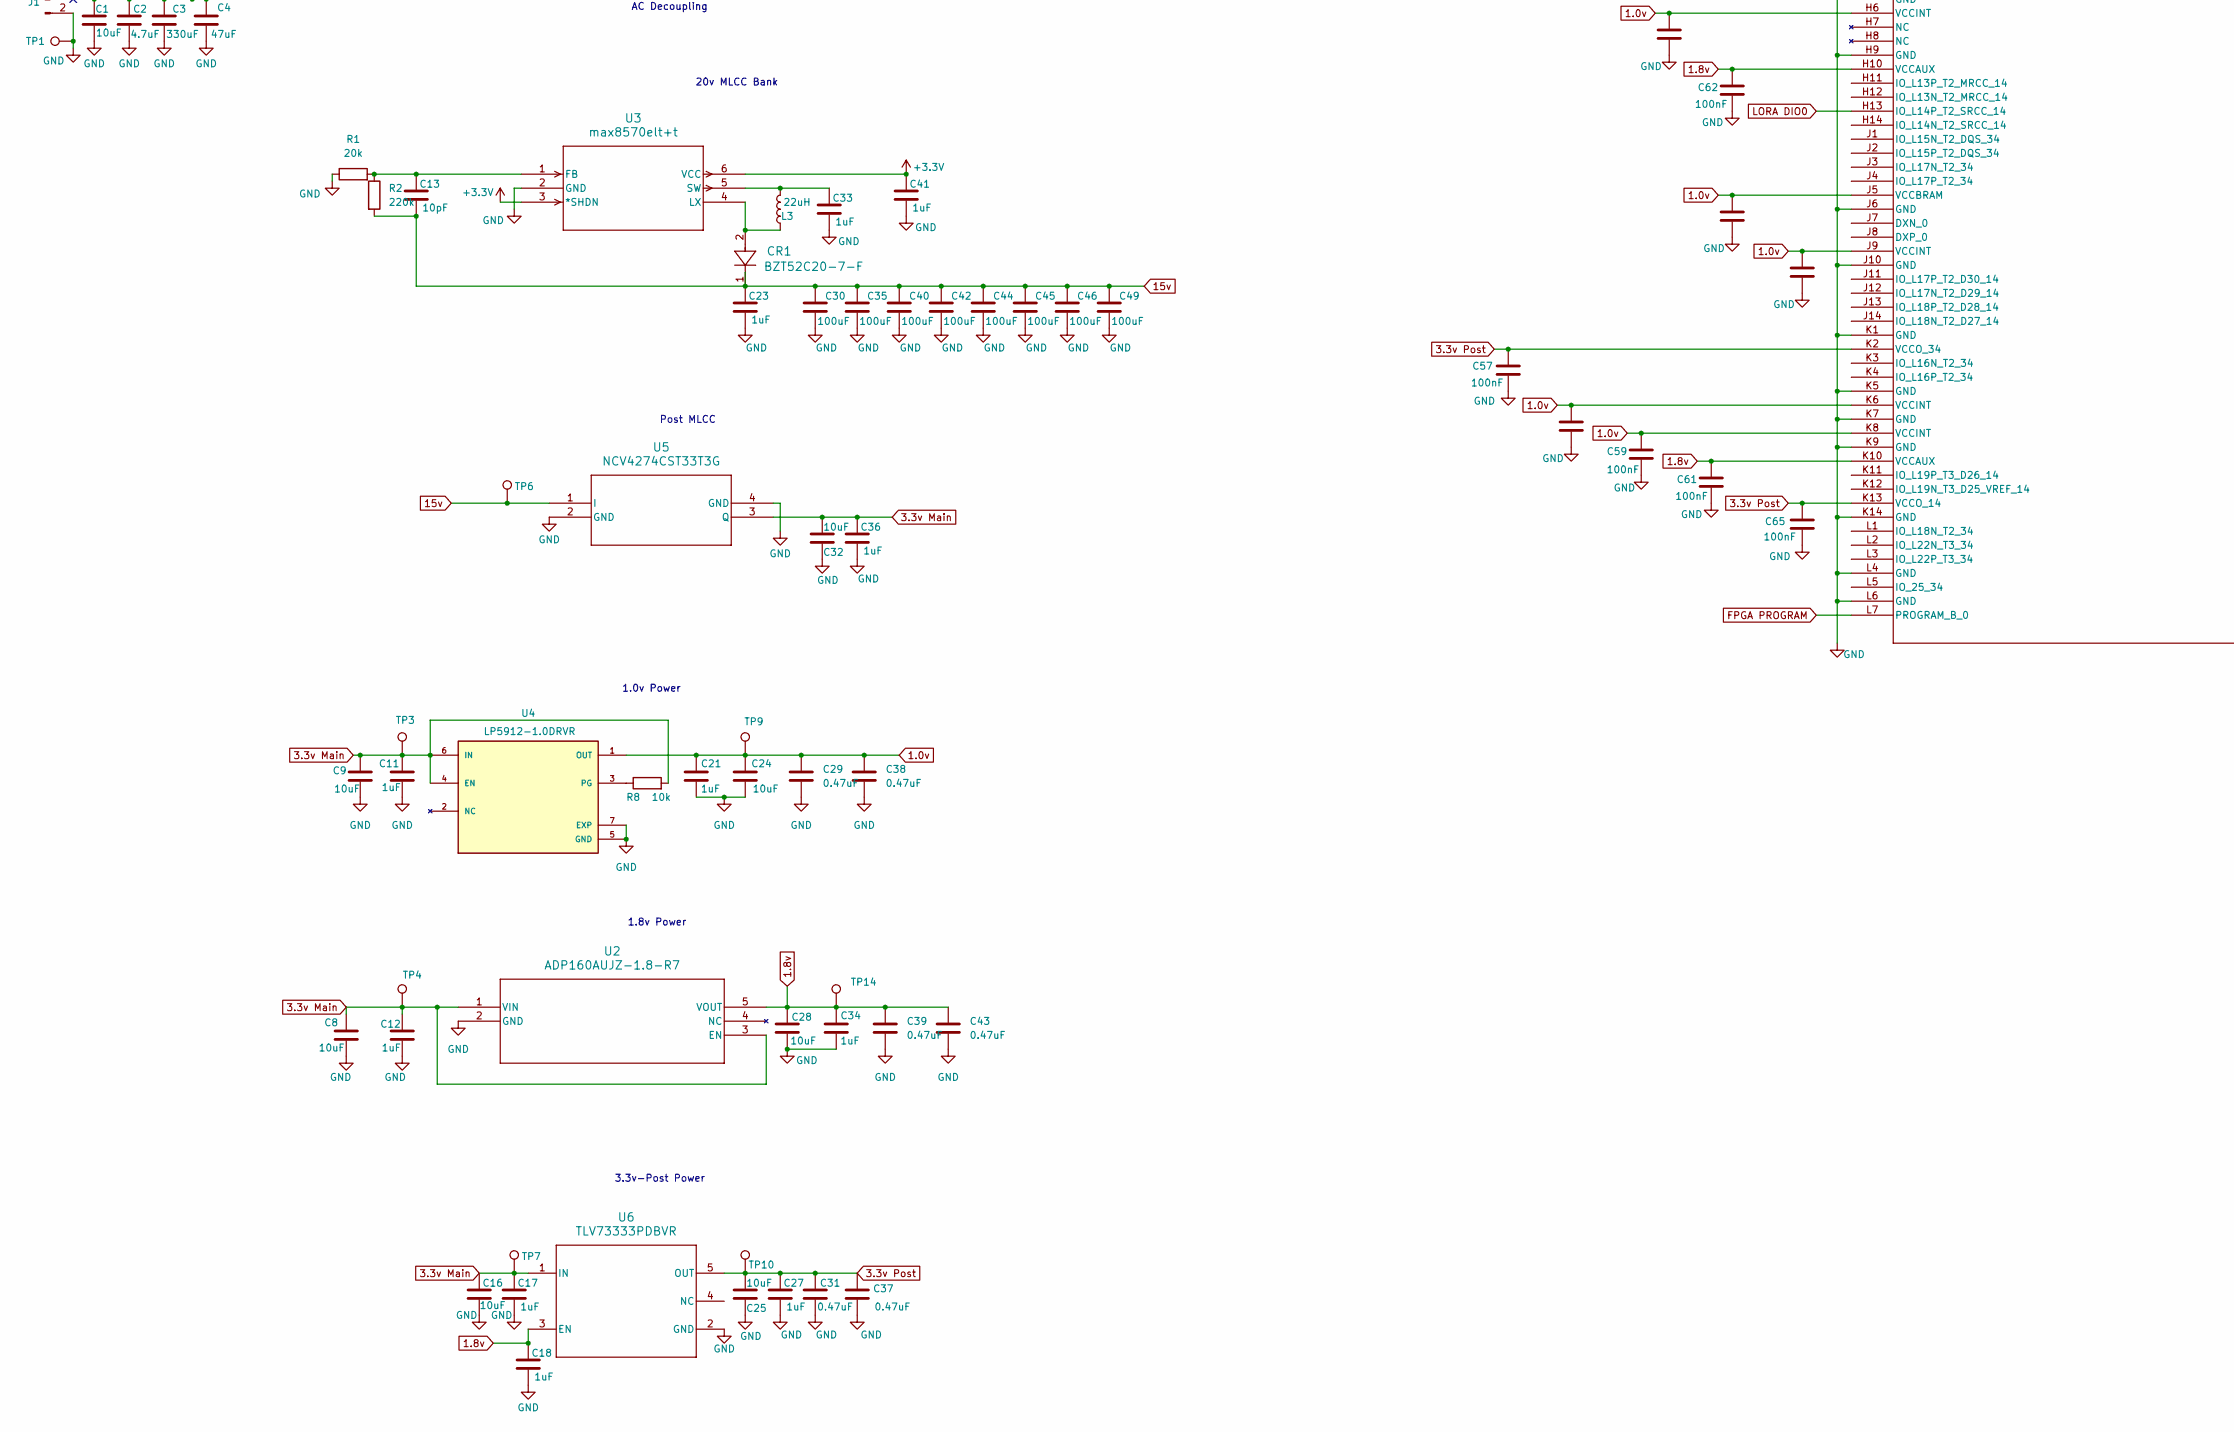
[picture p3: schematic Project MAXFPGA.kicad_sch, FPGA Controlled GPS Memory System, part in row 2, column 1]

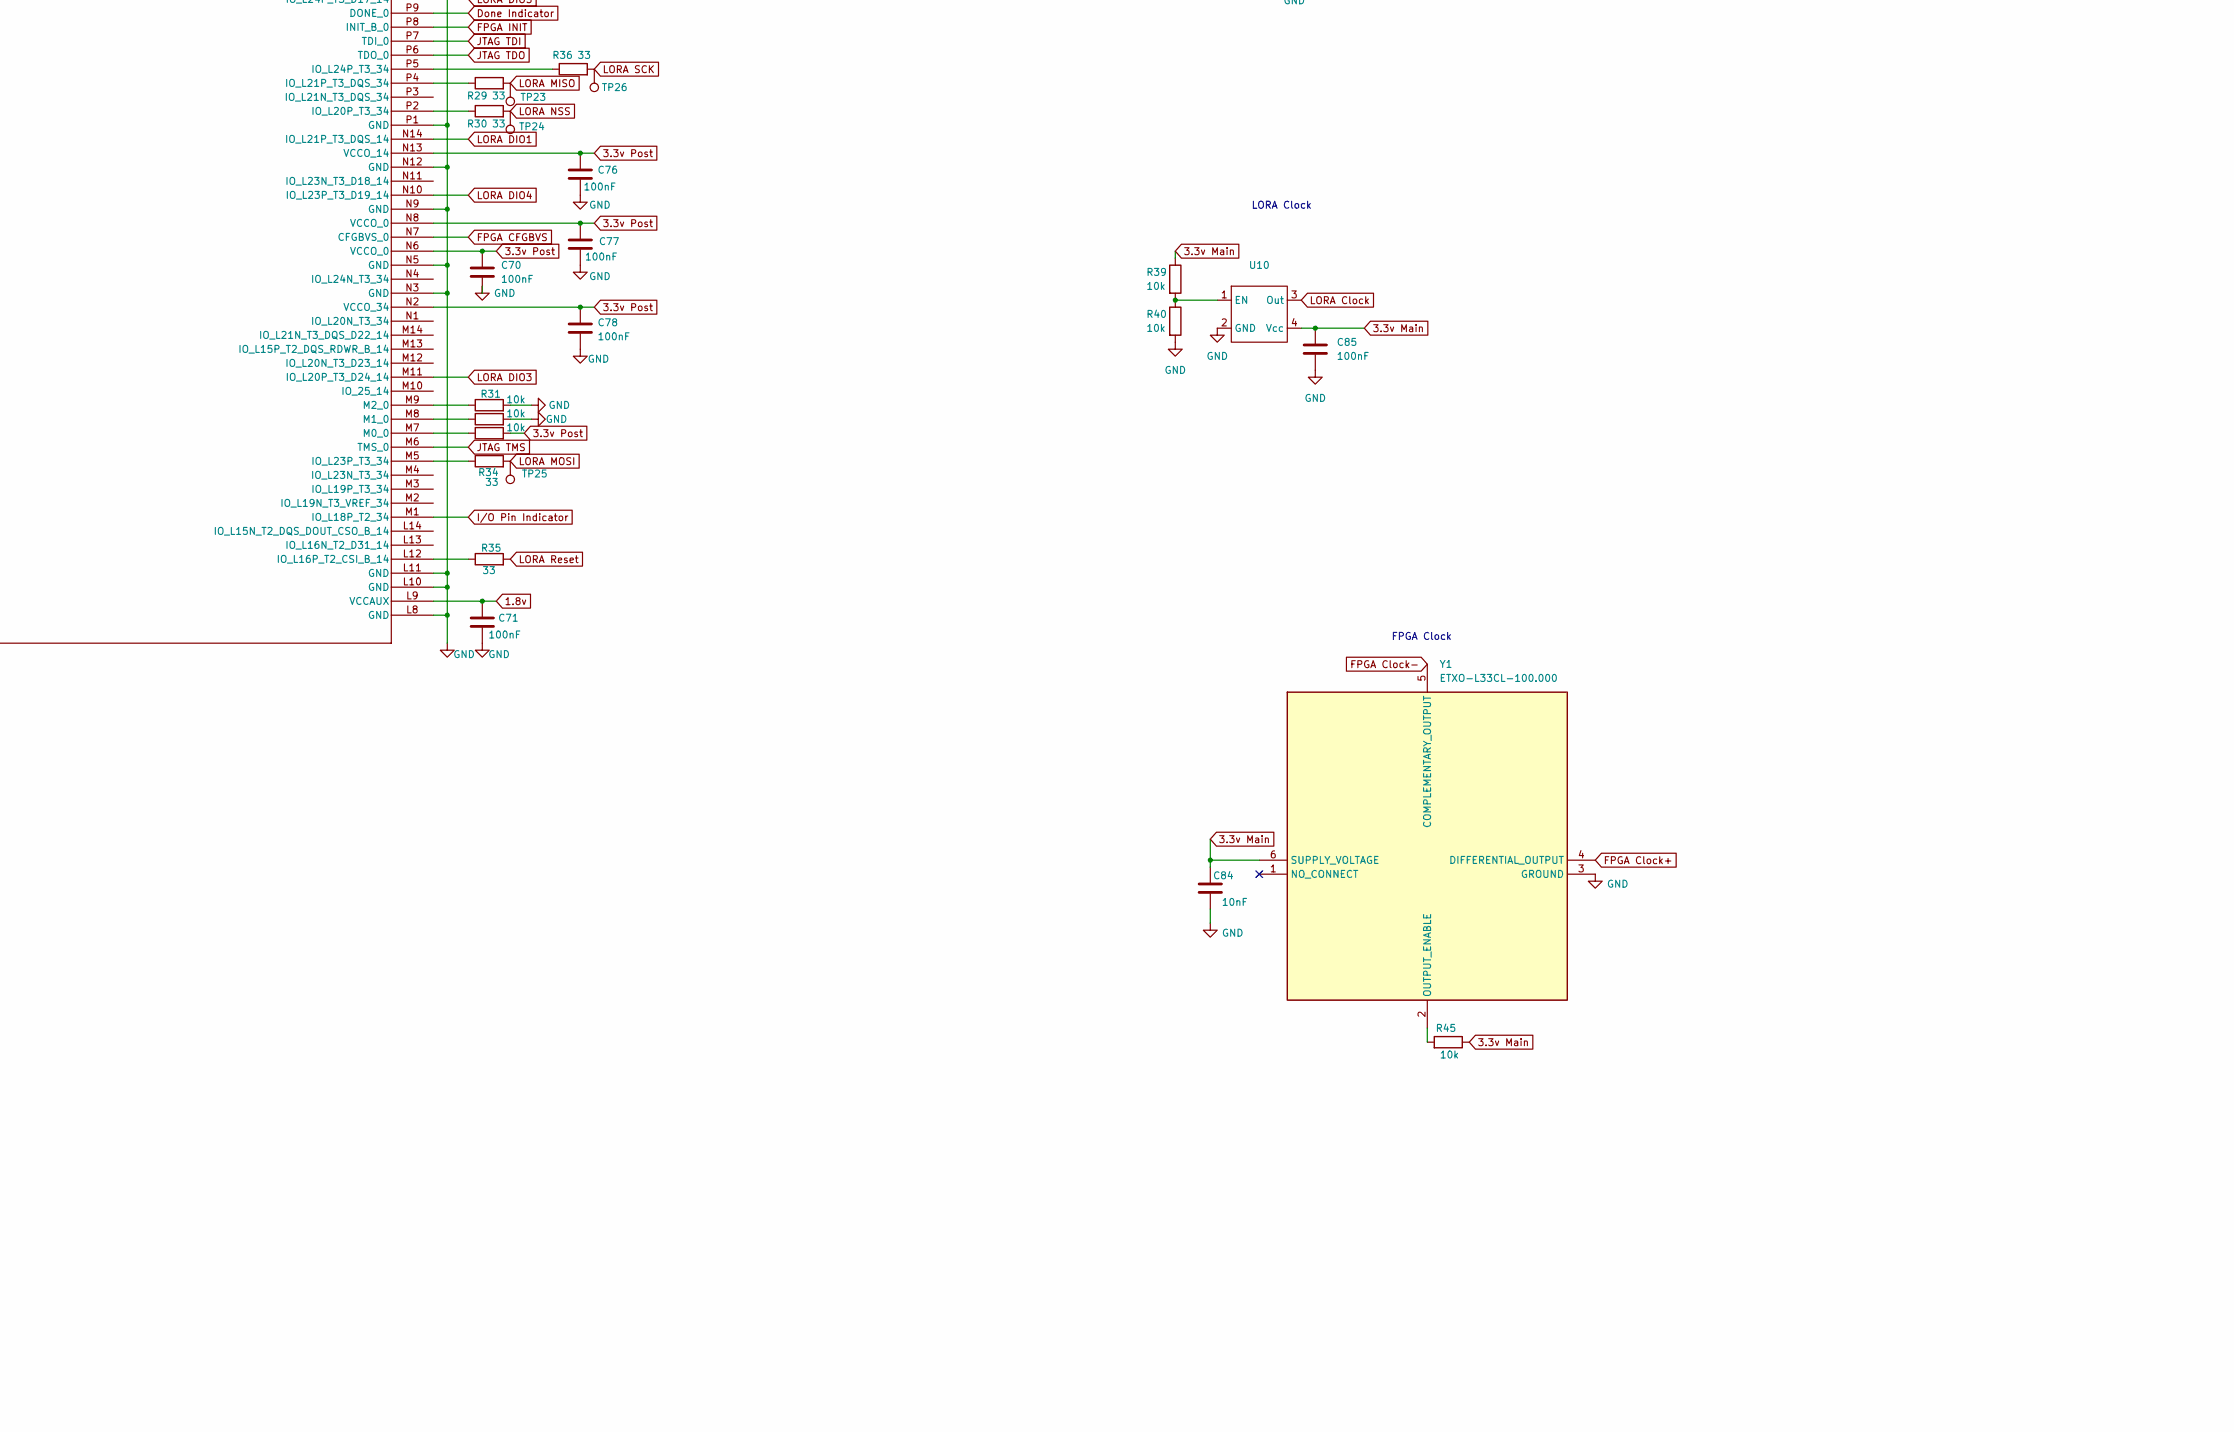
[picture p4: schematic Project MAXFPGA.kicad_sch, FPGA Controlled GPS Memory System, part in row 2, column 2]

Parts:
C1, C8, C9, C16, C24, C25, C28, C32: 10uF; C_0402_1005Metric
C2: 4.7uF; C_0402_1005Metric
C3: 330uF; C_1210_3225Metric
C4: 47uF; C_1206_3216Metric
C5, C84: 10nF; C_0402_1005Metric
C6, C7, C19, C22: 0.47nF; C_0402_1005Metric
C10: 1.7pF; C_0402_1005Metric
C11, C12, C17, C18, C21, C23, C27, C33, C34, C36, C41, C86: 1uF; C_0402_1005Metric
C13: 10pF; C_0402_1005Metric
C14: 1.1pF; C_0402_1005Metric
C15, C20, C57, C58, C59, C60, C61, C62, C63, C64, C65, C66, C67, C68, C69, C70, C71, C72, C73, C74, C75, C76, C77, C78, C79, C80, C81: 100nF; CAPC0603X33N_1
C26, C47, C51, C53, C54, C55, C56, C85, C87, C88, C89, C91, C93: 100nF; C_0402_1005Metric
C29, C31, C37, C38, C39, C43: 0.47uF; C_0402_1005Metric
C30, C35, C40, C42, C44, C45, C46, C49: 100uF; C_1210_3225Metric
C48: 15pF; CAPC17595_87N_KEM
C50, C100, C102, C104: 100pF; C_0402_1005Metric
C52: 0.75nF; C_0402_1005Metric
C82, C83, C92, C99, C101: 47pF; C_0402_1005Metric
C90: 47nF; C_0402_1005Metric
C94, C97: DNP; C_0402_1005Metric
C95: 5.6pF; C_0402_1005Metric
C96: 4.7pF; C_0402_1005Metric
C98: 12pF; C_0402_1005Metric
C103: 8.2pF; C_0402_1005Metric
C105, C106: 1nF; C_0402_1005Metric
C107, C108: 6.8pF; C_0402_1005Metric
CR1: BZT52C20-7-F; D_SOD-128
D1, D2, D3: LED; LED_SML-D12U1WT86
IC1: MT25QL128ABA1ESE-0SIT_TR; SOIC127P790X216-8N; Mouser Part Number 340-224871-REEL
J1: Conn_01x02_Pin; CONN2_M20-999_1x2_HRW
J2, J3, J5: MMCX-J-P-H-ST-SM1; MMCXJPHSTSM1; Mouser Part Number 200-MMCXJPHSTSM1
J4: 878311420; JTAG_Conn
L1: 5.6nH; INDC1006X60N_2
L2: 8.4nH; INDC1006X60N
L3: 22uH; L_0805_2012Metric
L4: 56nH; INDC1005X60N
L5: 30nH; INDC1006X60N_5
L6: 8.2nH; INDC1006X60N_3
L7: 18nH; INDC1006X60N_5
L8: 20nH; INDC1006X60N_4
Q1: DMP1045UQ-7; DONE_FET
R1: 20k; R_0402_1005Metric
R2: 220k; R_0402_1005Metric
R3: 100k; RESC1005X40N_5
R4, R5, R8, R9, R18, R21, R25, R31, R32, R33, R37, R39, R40, R45, R52, R53: 10k; RESC1005X40N_3
R6, R12, R13, R14, R15, R16, R17, R19, R20, R23, R24, R26, R27, R28, R29, R30, R34, R35, R36, R42, R44, R46, R48, R49, R50: 33; RESC1005X40N_2
R7, R10, R11: 330; RESC1005X40N_5
R22: 15k; RES_ERA2AEB153X
R38, R41, R43: 100k; RESC1005X40N_4
R47, R51: 0R; RESC1005X40N
SW1: PTS647SK38SMTR2LFS; PTS647SK38SMTR2LFS_CNK
TP1, TP2, TP3, TP4, TP5, TP6, TP7, TP8, TP9, TP10, TP11, TP12, TP13, TP14, TP15, TP16, TP17, TP18, TP19, TP20, TP21, TP22, TP23, TP24, TP25, TP26, TP27, TP28: TestPoint; TestPoint_Pad_1.0x1.0mm
U1: ECS-TXO-2520MV-320-AN-TR; SMD04_XTAL_2P5X2_ECS
U2: ADP160AUJZ-1.8-R7; 1.8V_REG
U3: max8570elt+t; 21-0164_L622&plus_1_MXM
U4: LP5912-1.0DRVR; SON65P200X200X80-7N; PARTREV D
U5: NCV4274CST33T3G; SOT-223_ONS
U6: TLV73333PDBVR; 3.3v_Reg
U7: MAX2771ETI_T; QFN50P500X500X80-29N
U8: XC7S15-1FTGB196C; FTGB196_AMD
U9: SX1276IMLTRT; QFN65P600X600X100-29N; PARTREV 5
U10: MP06838
U11: ASWD-S2-000
Y1: ETXO-L33CL-100.000; ETXOL33CL100000; Manufacturer_Part_Number ETXO-L33CL-100.000; Mouser Part Number 520-ETXO-L33CL-10000

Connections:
1.0v: C21.1, C24.1, C29.1, C38.1, C58.1, C59.1, C60.1, C63.1, C64.1, C66.2, C67.1, C69.1, C73.1, C74.1, C75.1, C80.1, C81.2, TP9.1 (1_1), U4.1 (OUT), U8.D6 (VCCINT), U8.D8 (VCCINT), U8.E5 (VCCBRAM), U8.E7 (VCCINT), U8.E9 (VCCINT), U8.F6 (VCCINT), U8.G5 (VCCBRAM), U8.G9 (VCCINT), U8.H6 (VCCINT), U8.J5 (VCCBRAM), U8.J9 (VCCINT), U8.K6 (VCCINT), U8.K8 (VCCINT)
1.8v: C18.1, C28.2, C34.2, C39.1, C43.1, C61.2, C62.1, C71.2, C79.2, TP14.1 (1_1), U2.5 (VOUT), U6.3 (EN), U8.F10 (VCCAUX), U8.H10 (VCCAUX), U8.K10 (VCCAUX), U8.L9 (VCCAUX)
3.3v Main: C8.1, C9.1, C11.1, C12.1, C16.1, C17.1, C32.1, C36.1, C47.1, C50.1, C51.1, C53.1, C54.1, C55.1, C56.1, C84.1, C85.1, C86.1, C87.1, C88.1, C89.1, C91.1, C93.1, C105.1, R8.2, R18.2, R21.2, R39.1, R45.1, TP3.1 (1_1), TP4.1 (1_1), TP7.1 (1_1), TP17.1 (1_1), TP28.1 (1_1), U1.4, U2.1 (VIN), U2.3 (EN), U4.4 (EN), U4.6 (IN), U5.3 (Q), U6.1 (IN), U7.2 (VCCCP), U7.6 (VCCD), U7.14 (VCCADC), U7.22 (VCCRF), U7.27 (VCCIF), U7.28 (VCCVCO), U9.2 (VR_ANA), U9.3 (VBAT_ANA), U9.4 (VR_DIG), U9.14 (VBAT_DIG), U9.24 (VBAT_RF), U10.4 (Vcc), U11.4 (VDD), Y1.6 (SUPPLY_VOLTAGE)
3.3v Post: C25.1, C26.1, C27.1, C31.1, C37.1, C57.1, C65.1, C68.1, C70.1, C72.1, C76.1, C77.1, C78.1, IC1.8 (VCC), J4.2, Q1.2, R4.2, R5.1, R9.1, R11.1, R25.1, R33.2, TP8.1 (1_1), TP10.1 (1_1), U6.5 (OUT), U8.G2 (VCCO_34), U8.G13 (VCCO_14), U8.K2 (VCCO_34), U8.K13 (VCCO_14), U8.N2 (VCCO_34), U8.N6 (VCCO_0), U8.N7 (CFGBVS_0), U8.N8 (VCCO_0), U8.N13 (VCCO_14); also elsewhere on the board
15v: C13.2, C23.1, C30.2, C35.2, C40.2, C42.2, C44.2, C45.2, C46.2, C49.2, CR1.1, R2.2, TP6.1 (1_1), U5.1 (I)
+3.3V: C1.2, C2.2, C3.2, C4.2, C41.1, J1.1, TP2.1 (1_1), U3.3 (*SHDN), U3.6 (VCC); also elsewhere on the board
Done Indicator: Q1.1, R3.1, U8.P9 (DONE_0)
FLASH CHIP SELECT: IC1.1 (S#), U8.C11 (IO_L6P_T0_FCS_B_14); also elsewhere on the board
FLASH Clock: IC1.6 (C), U8.A8 (CCLK_0); also elsewhere on the board
FLASH D0: IC1.5 (DQ0), U8.B11 (IO_L1P_T0_D00_MOSI_14); also elsewhere on the board
FLASH D1: IC1.2 (DQ1), U8.B12 (IO_L1N_T0_D01_DIN_14); also elsewhere on the board
FLASH D2: IC1.3 (W#/DQ2), U8.D10 (IO_L2P_T0_D02_14); also elsewhere on the board
FLASH D3: IC1.7 (HOLD#/DQ3), U8.C10 (IO_L2N_T0_D03_14); also elsewhere on the board
FPGA Clock+: U8.G4 (IO_L12P_T1_MRCC_34), Y1.4 (DIFFERENTIAL_OUTPUT)
FPGA Clock-: U8.F4 (IO_L12N_T1_MRCC_34), Y1.5 (COMPLEMENTARY_OUTPUT)
FPGA INIT: C15.1, R4.1, TP5.1 (1_1), U8.P8 (INIT_B_0)
FPGA PROGRAM: C20.1, R9.2, SW1.2, U8.L7 (PROGRAM_B_0); also elsewhere on the board
GND: C1.1, C2.1, C3.1, C4.1, C8.2, C9.2, C10.2, C11.2, C12.2, C14.2, C15.2, C16.2, C17.2, C18.2, C20.2, C21.2, C23.2, C24.2, C25.2, C26.2, C27.2, C28.1, C29.2, C30.1, C31.2, C32.2, C33.2, C34.1, C35.1, C36.2, C37.2, C38.2, C39.2, C40.1, C41.2, C42.1, C43.2, C44.1, C45.1, C46.1, C47.2, C48.2, C49.1, C50.2, C51.2, C52.2, C53.2, C54.2, C55.2, C56.2, C57.2, C58.2, C59.2, C60.2, C61.1, C62.2, C63.2, C64.2, C65.2, C66.1, C67.2, C68.2, C69.2, C70.2, C71.1, C72.2, C73.2, C74.2, C75.2, C76.2, C77.2, C78.2, C79.1, C80.2, C81.1, C82.1, C84.2, C85.2, C86.2, C87.2, C88.2, C89.2, C90.2, C91.2, C92.2, C93.2, C94.2, C97.2, C98.2, C103.2, C105.2, C106.2, C107.2, C108.2, D2.1 (K), D3.1 (K), IC1.4 (VSS), J1.2, J2.2, J2.3, J2.4, J2.5, J3.2, J3.3, J3.4, J3.5, J4.1, J4.3, J4.5, J4.7, J4.9, J4.12, J4.13, J4.14, J5.2, J5.3, J5.4, J5.5, L5.2, R1.1, R3.2, R7.2, R31.2, R32.2, R37.2, R38.1, R40.2, R41.2, R43.2, R53.2, SW1.3, TP1.1 (1_1), U1.2, U2.2 (GND), U3.2 (GND), U4.5 (GND), U4.7 (EXP), U5.2 (GND), U5.4 (GND), U6.2 (GND), U7.29 (EP), U8.A1 (GND), U8.A6 (GND), U8.A9 (GND), U8.A11 (GND), U8.A14 (GND), U8.B4 (GND), U8.B7 (GND), U8.B9 (GND), U8.C2 (GND), U8.C6 (GND), U8.C7 (GND), U8.C8 (GND), U8.C9 (GND), U8.C13 (GND), U8.D5 (GND), U8.D7 (GND), U8.D9 (GND), U8.D11 (GND), U8.E1 (GND), U8.E3 (GND), U8.E6 (GND), U8.E8 (GND), U8.E10 (GND), U8.E14 (GND), U8.F5 (GND), U8.F9 (GND), U8.G3 (GND), U8.G6 (GND), U8.G10 (GND), U8.G12 (GND), U8.H5 (GND), U8.H9 (GND), U8.J6 (GND), U8.J10 (GND), U8.K1 (GND), U8.K5 (GND), U8.K7 (GND), U8.K9 (GND), U8.K14 (GND), U8.L4 (GND), U8.L6 (GND), U8.L8 (GND), U8.L10 (GND), U8.L11 (GND), U8.N3 (GND), U8.N5 (GND), U8.N9 (GND), U8.N12 (GND), U8.P1 (GND), U8.P14 (GND), U9.15 (GND), U9.23 (GND__1), U9.26 (GND__2), U9.29 (GND__3), U10.2 (GND), U11.2 (GND), Y1.3 (GROUND); also elsewhere on the board
I/O Pin Indicator: R10.1, U8.M1 (IO_L18P_T2_34)
JTAG TCK: R17.1, U8.A7 (TCK_0)
JTAG TDI: R20.1, R21.1, U8.P7 (TDI_0)
JTAG TDO: R19.1, U8.P6 (TDO_0)
JTAG TMS: R14.1, R18.1, U8.M6 (TMS_0)
LORA Clock: U9.5 (XTA), U10.3 (Out)
LORA DIO0: R50.2, U8.H13 (IO_L14P_T2_SRCC_14)
LORA DIO1: R49.2, U8.N14 (IO_L21P_T3_DQS_14)
LORA DIO2: R48.2, U8.P12 (IO_L22P_T3_D21_14)
LORA DIO3: R46.2, U8.M11 (IO_L20P_T3_D24_14)
LORA DIO4: R44.2, U8.N10 (IO_L23P_T3_D19_14)
LORA DIO5: R42.2, U8.P10 (IO_L24P_T3_D17_14)
LORA MISO: R29.2, TP23.1 (1_1), U9.17 (MISO)
LORA MOSI: R34.2, TP25.1 (1_1), U9.18 (MOSI)
LORA NSS: R30.2, TP24.1 (1_1), U9.19 (NSS)
LORA Reset: R35.2, R37.1, TP27.1 (1_1), U9.7 (NRESET)
LORA SCK: R36.2, TP26.1 (1_1), U9.16 (SCK)
MAX2771 CLKIN: R24.1, TP18.1 (1_1), U7.5 (ADC_CLKIN)
MAX2771 CLKOUT: R6.1, TP20.1 (1_1), U8.D1 (IO_L11P_T1_SRCC_34)
MAX2771 CSN: R27.2, TP21.1 (1_1), U7.9 (CSN)
MAX2771 I0: R15.2, U8.B5 (IO_L4P_T0_34)
MAX2771 I1: R16.2, U8.C5 (IO_L6P_T0_34)
MAX2771 LD: R23.1, TP13.1 (1_1), U7.17 (LD)
MAX2771 Q0: R12.2, U8.A4 (IO_L2P_T0_34)
MAX2771 Q1: R13.2, U8.F3 (IO_L8P_T1_34)
MAX2771 SCLK: R26.1, TP19.1 (1_1), U7.8 (SCLK)
MAX2771 SDATA: R28.2, TP22.1 (1_1), U7.7 (SDATA)
unnamed: C5.2, U1.3
unnamed 46: C6.1, J2.1; also elsewhere on the board
unnamed 47: C7.1, J3.1; also elsewhere on the board
unnamed: C6.2, C10.1, L1.1
unnamed: C7.2, C14.1, L2.1
unnamed: C52.1, R22.2
unnamed: C83.1, C95.1, L5.1
unnamed: C94.1, C96.1, L4.2, L6.1, R47.2
unnamed: C95.2, C97.1, C99.1
unnamed: C99.2, R51.1
unnamed: C96.2, C98.1, C100.1, L6.2
unnamed: C100.2, L7.1
unnamed: C101.1, R51.2
unnamed: C102.2, C103.1, L7.2
unnamed: C104.2, C107.1, L8.2
unnamed 60: C108.1, J5.1, L8.1; also elsewhere on the board
unnamed: D1.2 (A), Q1.3
unnamed: D1.1 (K), R7.1
unnamed: D2.2 (A), R10.2
unnamed: D3.2 (A), R11.2
unnamed 65: J4.4, R14.2; also elsewhere on the board
unnamed 66: J4.6, R17.2; also elsewhere on the board
unnamed 67: J4.8, R19.2; also elsewhere on the board
unnamed 68: J4.10, R20.2; also elsewhere on the board
unnamed: C13.1, R1.2, R2.1, U3.1 (FB)
unnamed: CR1.2, L3.1, U3.4 (LX)
unnamed: C33.1, L3.2, U3.5 (SW)
unnamed: R8.1, U4.3 (PG)
unnamed: R6.2, U7.4 (CLKOUT)
unnamed: C48.1, R22.1, U7.1 (CPOUT)
unnamed: R15.1, TP15.1 (1_1), U7.12 (I0)
unnamed: R16.1, TP16.1 (1_1), U7.13 (I1)
unnamed: L1.2, U7.19 (LNAIN_HI)
unnamed: L2.2, U7.20 (LNAIN_LO)
unnamed: C19.2, U7.24 (LNAOUT_HI)
unnamed: C22.2, U7.23 (LNAOUT_LO)
unnamed: C19.1, U7.25 (MIXIN_HI)
unnamed: C22.1, U7.26 (MIXIN_LO)
unnamed: R12.1, TP11.1 (1_1), U7.11 (Q0)
unnamed: R13.1, TP12.1 (1_1), U7.10 (Q1)
unnamed: R5.2, U7.18 (SHDN)
unnamed: C5.1, U7.3 (XTAL)
unnamed: R26.2, U8.D3 (IO_L1P_T0_34)
unnamed: R25.2, U8.B10 (IO_L3P_T0_DQS_PUDC_B_14)
unnamed: R23.2, U8.A12 (IO_L4P_T0_D04_14)
unnamed: R24.2, U8.B2 (IO_L5P_T0_34)
unnamed: R27.1, U8.E4 (IO_L7P_T1_34)
unnamed: R28.1, U8.E2 (IO_L10P_T1_34)
unnamed: R35.1, U8.L12 (IO_L16P_T2_CSI_B_14)
unnamed: R30.1, U8.P2 (IO_L20P_T3_34)
unnamed: R29.1, U8.P4 (IO_L21P_T3_DQS_34)
unnamed: R34.1, U8.M5 (IO_L23P_T3_34)
unnamed: R36.1, U8.P5 (IO_L24P_T3_34)
unnamed: R33.1, U8.M7 (M0_0)
unnamed: R32.1, U8.M8 (M1_0)
unnamed: R31.1, U8.M9 (M2_0)
unnamed: R50.1, U9.8 (DIO0)
unnamed: R49.1, U9.9 (DIO1/DCLK)
unnamed: R48.1, U9.10 (DIO2/DATA)
unnamed: R46.1, U9.11 (DIO3)
unnamed: R44.1, U9.12 (DIO4)
unnamed: R42.1, U9.13 (DIO5)
unnamed: R47.1, U9.27 (PA_BOOST)
unnamed: C82.2, U9.21 (RFI_HF)
unnamed: C83.2, U9.1 (RFI_LF)
unnamed: R43.1, U9.22 (RFO_HF)
unnamed: R41.1, U9.28 (RFO_LF)
unnamed: R52.2, U9.20 (RXTX/RF_MOD)
unnamed: C90.1, C92.1, L4.1, U9.25 (VR_PA)
unnamed: R38.2, U9.6 (XTB)
unnamed: R39.2, R40.1, U10.1 (EN)
unnamed: C104.1, U11.5 (ANT)
unnamed: C102.1, U11.3 (RF1)
unnamed: C101.2, U11.1 (RF2)
unnamed: C106.1, R52.1, R53.1, U11.6 (VCTL)
unnamed: R45.2, Y1.2 (OUTPUT_ENABLE)

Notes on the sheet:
1.0v Power
Values from SX1276 Reference Design
Post-Sequence Power Indicator LED
FPGA FLASH
FPGA Config
LPF/Matching
Post MLCC
LORA Clock
TANK Band Pass Filter
20v MLCC Bank
FPGA
AC Decoupling
FPGA Clock
1.8v Power
I/O Pin Indicator LED
Input
FPGA Configuration Indicator LED
Matching
Matching
AC Coupling
Voltage Divider 10k/10k
3.3v-Post Power
JTAG Connector
Loop Filter
MAX2771 Reference Clock
Bias Tee
LORA

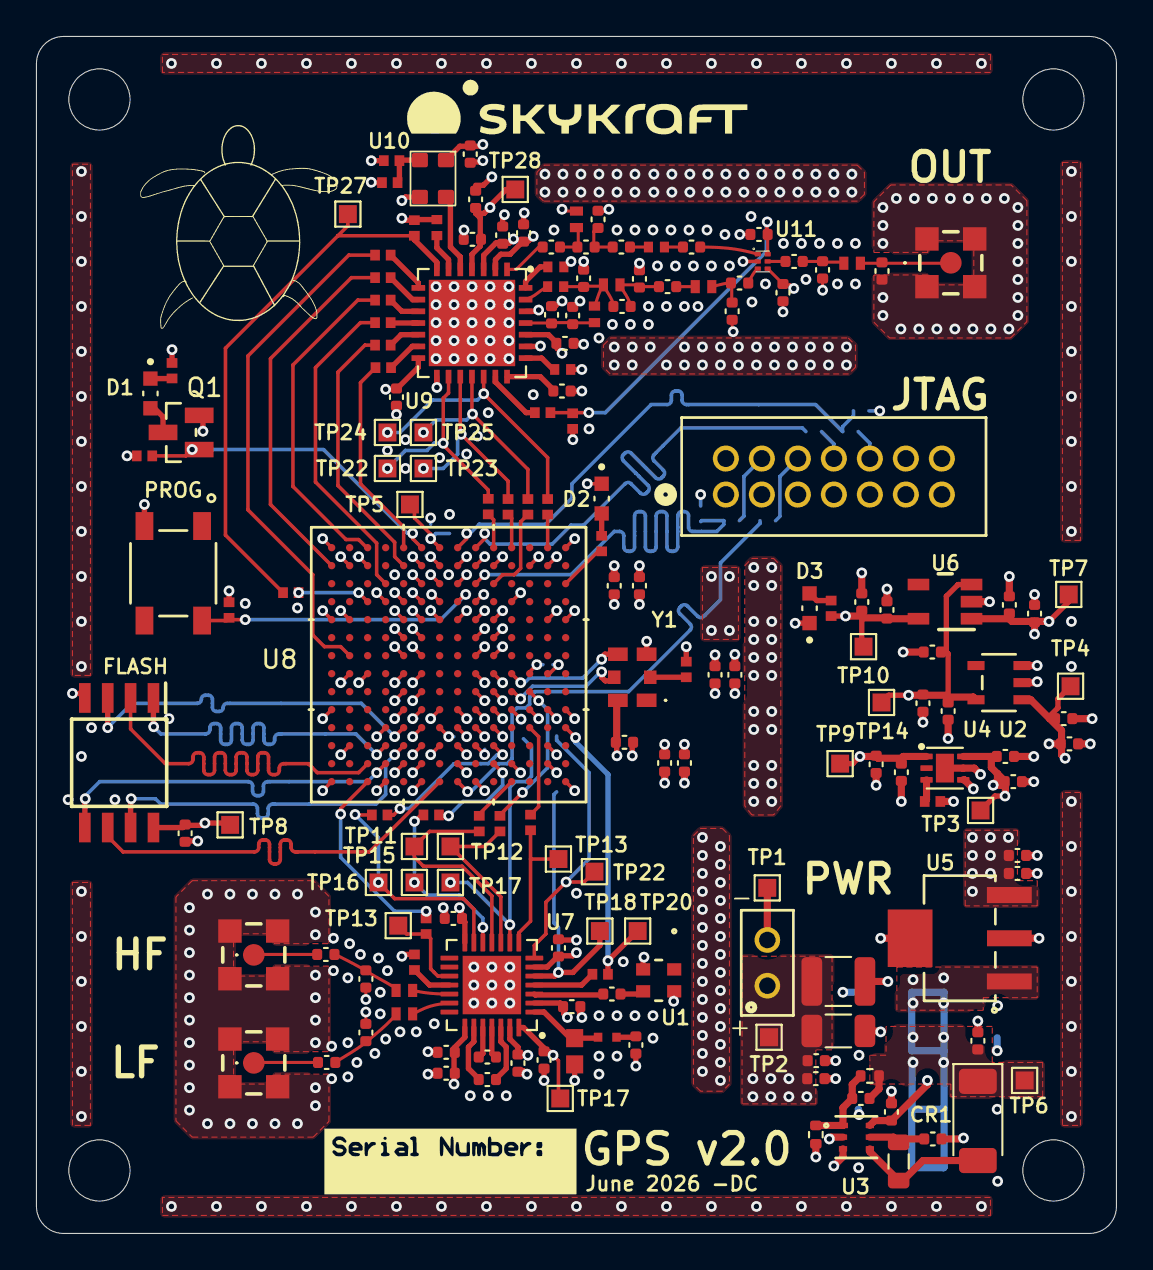
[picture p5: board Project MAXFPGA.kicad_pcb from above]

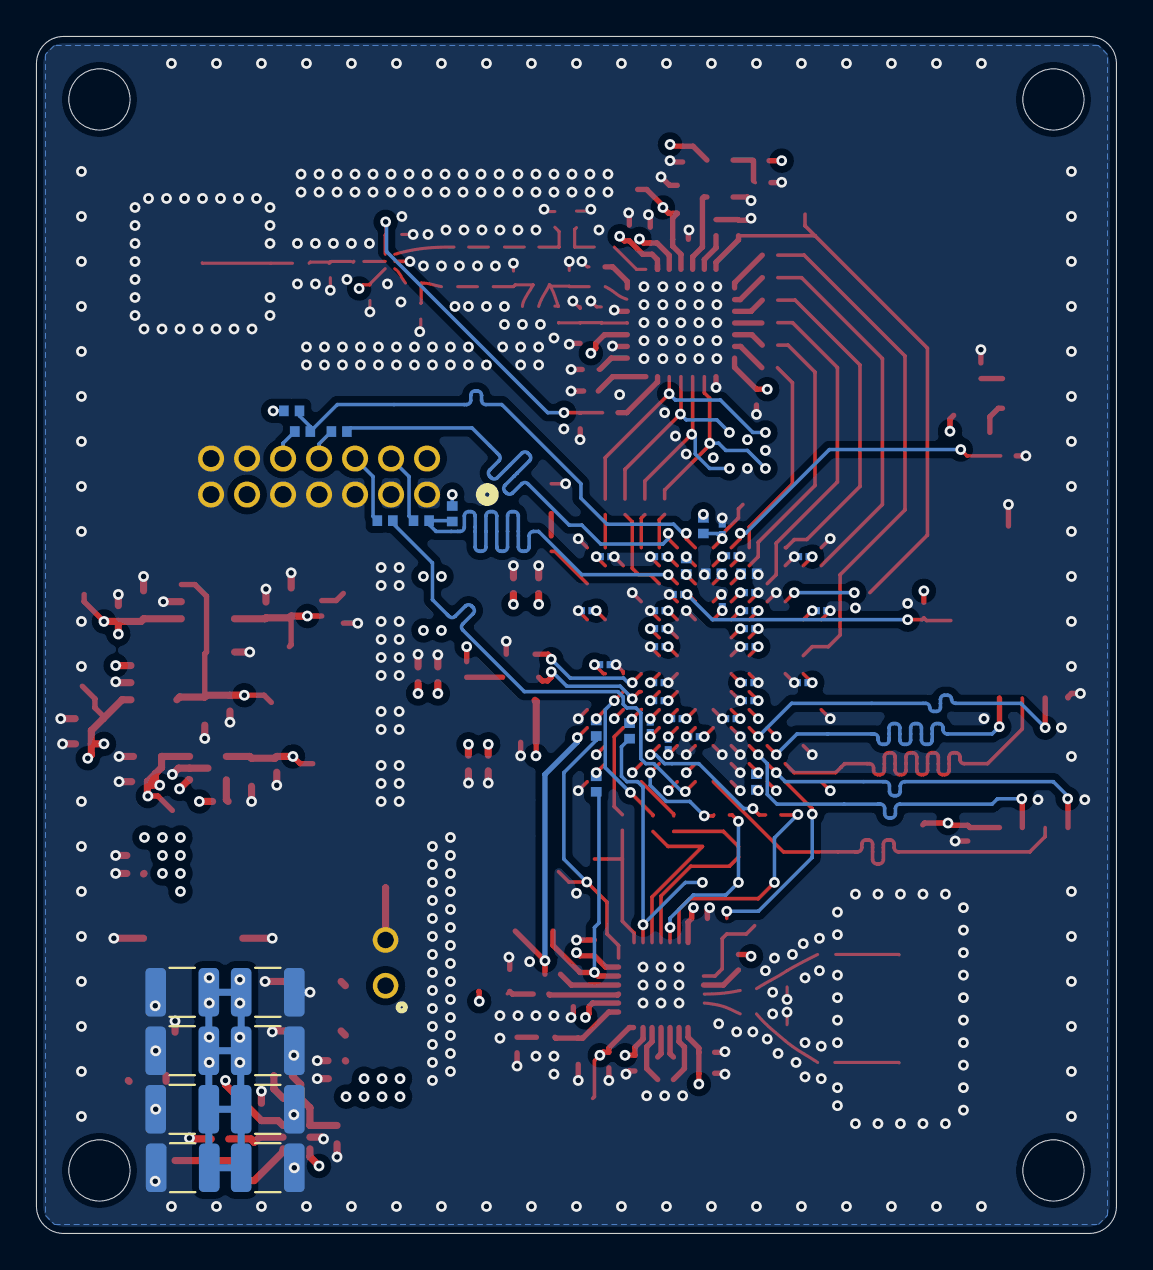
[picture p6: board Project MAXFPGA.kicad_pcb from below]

Board: 4 copper layers, 60.0 x 66.5 mm, 221 parts (49 on the bottom side), 117 nets.

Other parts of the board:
FLASH: MT25QL128ABA1ESE-0SIT_TR; SOIC127P790X216-8N
HF: MMCX-J-P-H-ST-SM1; MMCXJPHSTSM1
JTAG: 878311420; JTAG_Conn
LF: MMCX-J-P-H-ST-SM1; MMCXJPHSTSM1
OUT: MMCX-J-P-H-ST-SM1; MMCXJPHSTSM1
PROG: PTS647SK38SMTR2LFS; PTS647SK38SMTR2LFS_CNK
PWR: Conn_01x02_Pin; CONN2_M20-999_1x2_HRW

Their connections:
3.3v Post: FLASH.8 (VCC), JTAG.2; also elsewhere on the board
+3.3V: PWR.1; also elsewhere on the board
FLASH CHIP SELECT: FLASH.1 (S#); also elsewhere on the board
FLASH Clock: FLASH.6 (C); also elsewhere on the board
FLASH D0: FLASH.5 (DQ0); also elsewhere on the board
FLASH D1: FLASH.2 (DQ1); also elsewhere on the board
FLASH D2: FLASH.3 (W#/DQ2); also elsewhere on the board
FLASH D3: FLASH.7 (HOLD#/DQ3); also elsewhere on the board
FPGA PROGRAM: PROG.2; also elsewhere on the board
GND: FLASH.4 (VSS), HF.2, HF.3, HF.4, HF.5, JTAG.1, JTAG.3, JTAG.5, JTAG.7, JTAG.9, JTAG.12, JTAG.13, JTAG.14, LF.2, LF.3, LF.4, LF.5, OUT.2, OUT.3, OUT.4, OUT.5, PROG.3, PWR.2; also elsewhere on the board
unnamed 46: HF.1; also elsewhere on the board
unnamed 47: LF.1; also elsewhere on the board
unnamed 60: OUT.1; also elsewhere on the board
unnamed 65: JTAG.4; also elsewhere on the board
unnamed 66: JTAG.6; also elsewhere on the board
unnamed 67: JTAG.8; also elsewhere on the board
unnamed 68: JTAG.10; also elsewhere on the board

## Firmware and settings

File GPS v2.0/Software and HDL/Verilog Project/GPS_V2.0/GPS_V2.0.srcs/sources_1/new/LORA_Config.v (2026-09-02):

`timescale 1ns / 1ps
//////////////////////////////////////////////////////////////////////////////////
// Company:         Skykraft
// Engineer:        Dino Colling
// 
// Create Date:     16.12.2025 14:55:20
// Design Name: 
// Module Name:     LORA_Config
// Project Name:    Turtle GPS
// Target Devices: 
// Tool Versions: 
// Description:     Configures the LoRa module upon trigger
// 
// Dependencies:    None
// 
// Revision:
// Revision 0.01 - File Created
// Additional Comments:
// 
//////////////////////////////////////////////////////////////////////////////////


module LORA_Config(
        input wire      clk,
        input wire      SPI_Tick,
        input wire      LORA_CONFIG_BEGIN,   //Trigger for Module
        input wire      reset,
        output wire     CSN,
        output wire     SDATA,
        output wire     SCLK_en_config
    );
    

    //--------------------------------------------------------------------------------------------------
    //  States
    //--------------------------------------------------------------------------------------------------

    parameter [1:0]     idle    = 2'b00,    //Holds and initialises before moving to start
                        start   = 2'b01,    //Write bit and Address
                        data    = 2'b10,    //Data bits then move to stop
                        stop    = 2'b11;    //Stop bits
                    
    
    //--------------------------------------------------------------------------------------------------
    //  Registers and Variables
    //--------------------------------------------------------------------------------------------------

    reg [1:0]   state               = idle, 
                state_next;
    reg [6:0]   address, 
                address_next;
    reg [7:0]   data_bits, 
                data_bits_next;
    
    reg [6:0]   address_memory    [0:26];
    reg [7:0]   data_memory       [0:26];
    
    reg         CSN_reg             = 1,
                CSN_reg_next;
    reg         SDATA_reg           = 0, 
                SDATA_reg_next;
    reg         SCLK_en             = 0, 
                SCLK_en_next;
    
    reg [12:0]  bit                 = 0,
                bit_next;
    reg [7:0]   LoRa_register_index = 0, 
                LoRa_register_index_next;

    integer i;
    

    //--------------------------------------------------------------------------------------------------
    //  Initialisation
    //--------------------------------------------------------------------------------------------------
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

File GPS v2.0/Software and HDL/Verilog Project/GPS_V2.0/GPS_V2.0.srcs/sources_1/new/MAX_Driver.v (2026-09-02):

`timescale 1ns / 1ps
//////////////////////////////////////////////////////////////////////////////////
// Company:         Skykraft
// Engineer:        Dino Colling
// 
// Create Date:     16.12.2025 14:04:24
// Design Name: 
// Module Name:     MAX_Driver
// Project Name:    Turtle GPS
// Target Devices: 
// Tool Versions: 
// Description:     MAX2771 chip config driver
// 
// Dependencies:    None
// 
// Revision:
// Revision 0.01 - File Created
// Additional Comments:
// 
//////////////////////////////////////////////////////////////////////////////////


module MAX_Driver(
        input wire      clk,
        input wire      MAX_CONFIG_BEGIN,
        input wire      reset,
        input wire      SPI_Tick,
        output wire     MAX_SDATA,
        output wire     MAX_SCLK,
        output wire     MAX_CSN
    );
    

    //--------------------------------------------------------------------------------------------------
    //  States
    //--------------------------------------------------------------------------------------------------

    parameter [1:0] idle    = 2'b00,
                    start   = 2'b01,    //Start will initialise, address and select write
                    data    = 2'b10,    //This will transmit the data for the 32 bit register
                    stop    = 2'b11;    //Ends the transfer
    

    //--------------------------------------------------------------------------------------------------
    //  Registers
    //--------------------------------------------------------------------------------------------------

    reg [1:0]   state               = idle, 
                state_next;
    reg [3:0]   address, 
                address_next;               //This will cycle through the 10 address registers
    reg [31:0]  data_bits, 
                data_bits_next;             //This will cycle through the data for each address
    
    reg [3:0]   address_memory  [0:10];
    reg [31:0]  data_memory     [0:10];
    
    reg         CSN_reg             = 1, 
                CSN_reg_next;
    reg         SDATA_reg           = 1'bz, 
                SDATA_reg_next;
    reg         SCLK_en             = 0, 
                SCLK_en_next;
    
    reg [5:0]   bit                 = 0, 
                bit_next;
    reg [3:0]   max_register_index  = 0, 
                max_register_index_next;
    

    //--------------------------------------------------------------------------------------------------
    //  Initialisation
    //--------------------------------------------------------------------------------------------------

    initial 
    begin
        address_memory[0]       = 4'h0;
        address_memory[1]       = 4'h1;
        address_memory[2]       = 4'h2;
        address_memory[3]       = 4'h3;
        address_memory[4]       = 4'h4;
        address_memory[5]       = 4'h5;
        address_memory[6]       = 4'h6;
        address_memory[7]       = 4'h7;
        address_memory[8]       = 4'h8;
        address_memory[9]       = 4'h9;
        address_memory[10]      = 4'hA;
        
        data_memory[0]          = 32'hBEA41503;     // Centre at 4.29 MHz
        data_memory[1]          = 32'h28550288;     // Config Register 2
        data_memory[2]          = 32'h0EAFB1F4;
        data_memory[3]          = 32'h498C0008;     //REFDIV = *0.5  for 16 MHz
        data_memory[4]          = 32'h00B820F0;     //RDIV = 30 PLL      Integer Division Ratio = 1473 to give  1571.2 - real value is 1571.1
        data_memory[5]          = 32'h06B85270;     //PLL Fractional Division Ratio = 0.42
        data_memory[6]          = 32'h08000000;
        data_memory[7]          = 32'h03FC73C2;     //To give ADC clock at 16 MHz, MCOUNT = 1851, LCOUNT = 1347 for ADC
        data_memory[8]          = 32'h01E0F401;
        data_memory[9]          = 32'h00C00002;
        data_memory[10]         = 32'h08027FE4;     //Disable dividers for 16 MHz Clock, MCOUNT = 2046, LCOUNT = 2050 for ADC, ADC clock on Clock Out
        
        //Assigns default values to next-state variables
        state_next              <= idle;
        
        SDATA_reg_next          <= 1'bz;
        SCLK_en_next            <= 0;
        
        bit_next                <= 0;
        max_register_index_next <= 0;
        
        address_next            <= 4'h0;
        data_bits_next          <= 32'hBEA41503;
    end
    

    //--------------------------------------------------------------------------------------------------
    //  Sequential Logic
    //--------------------------------------------------------------------------------------------------

    always @(posedge clk) 
    begin
        if (reset == 1)
        begin
            state                   <= idle;
                
            CSN_reg                 <= 1;
            SDATA_reg               <= 1'bz;
            SCLK_en                 <= 0;
                
            bit                     <= 0;
            max_register_index      <= 0;
        end
        else
        begin
            state                   <= state_next;
            address                 <= address_next;
            data_bits               <= data_bits_next;
                
            CSN_reg                 <= CSN_reg_next;
            SDATA_reg               <= SDATA_reg_next;
            SCLK_en                 <= SCLK_en_next;
                
            bit                     <= bit_next;
            max_register_index      <= max_register_index_next;
        end
    end
    

    //--------------------------------------------------------------------------------------------------
    //  Sequential Logic with Statemachine
    //--------------------------------------------------------------------------------------------------
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

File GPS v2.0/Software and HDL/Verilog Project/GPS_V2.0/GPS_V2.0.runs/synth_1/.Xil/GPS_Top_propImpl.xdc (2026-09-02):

set_property SRC_FILE_INFO {cfile:C:/Users/DinoColling/GPS_V2.0/GPS_V2.0.srcs/constrs_1/new/design.xdc rfile:../../../GPS_V2.0.srcs/constrs_1/new/design.xdc id:1} [current_design]
set_property src_info {type:XDC file:1 line:2 export:INPUT save:INPUT read:READ} [current_design]
set_property -dict { PACKAGE_PIN G4   IOSTANDARD LVCMOS33 } [get_ports { clk }];
set_property src_info {type:XDC file:1 line:6 export:INPUT save:INPUT read:READ} [current_design]
set_property -dict { PACKAGE_PIN B5   IOSTANDARD LVCMOS33 } [get_ports { I0 }];
set_property src_info {type:XDC file:1 line:7 export:INPUT save:INPUT read:READ} [current_design]
set_property -dict { PACKAGE_PIN C5   IOSTANDARD LVCMOS33 } [get_ports { I1 }];
set_property src_info {type:XDC file:1 line:8 export:INPUT save:INPUT read:READ} [current_design]
set_property -dict { PACKAGE_PIN A4   IOSTANDARD LVCMOS33 } [get_ports { Q0 }];
set_property src_info {type:XDC file:1 line:9 export:INPUT save:INPUT read:READ} [current_design]
set_property -dict { PACKAGE_PIN F3   IOSTANDARD LVCMOS33 } [get_ports { Q1 }];
set_property src_info {type:XDC file:1 line:10 export:INPUT save:INPUT read:READ} [current_design]
set_property -dict { PACKAGE_PIN D1   IOSTANDARD LVCMOS33 } [get_ports { ADC_CLK }];
set_property src_info {type:XDC file:1 line:11 export:INPUT save:INPUT read:READ} [current_design]
set_property -dict { PACKAGE_PIN D3   IOSTANDARD LVCMOS33 } [get_ports { MAX_SCLK }];
set_property src_info {type:XDC file:1 line:12 export:INPUT save:INPUT read:READ} [current_design]
set_property -dict { PACKAGE_PIN E2   IOSTANDARD LVCMOS33 } [get_ports { MAX_SDATA }];
set_property src_info {type:XDC file:1 line:13 export:INPUT save:INPUT read:READ} [current_design]
set_property -dict { PACKAGE_PIN E4   IOSTANDARD LVCMOS33 } [get_ports { MAX_CSN }];
set_property src_info {type:XDC file:1 line:14 export:INPUT save:INPUT read:READ} [current_design]
set_property -dict { PACKAGE_PIN L12  IOSTANDARD LVCMOS33 } [get_ports { LORA_RESET }];
set_property src_info {type:XDC file:1 line:15 export:INPUT save:INPUT read:READ} [current_design]
set_property -dict { PACKAGE_PIN M5   IOSTANDARD LVCMOS33 } [get_ports { LORA_SDATA }];
set_property src_info {type:XDC file:1 line:16 export:INPUT save:INPUT read:READ} [current_design]
set_property -dict { PACKAGE_PIN P2   IOSTANDARD LVCMOS33 } [get_ports { LORA_CSN }];
set_property src_info {type:XDC file:1 line:17 export:INPUT save:INPUT read:READ} [current_design]
set_property -dict { PACKAGE_PIN P4   IOSTANDARD LVCMOS33 } [get_ports { LORA_MISO }];
set_property src_info {type:XDC file:1 line:18 export:INPUT save:INPUT read:READ} [current_design]
set_property -dict { PACKAGE_PIN P5   IOSTANDARD LVCMOS33 } [get_ports { LORA_SCLK }];
set_property src_info {type:XDC file:1 line:19 export:INPUT save:INPUT read:READ} [current_design]
set_property -dict { PACKAGE_PIN H13  IOSTANDARD LVCMOS33 } [get_ports { DIO0 }];
set_property src_info {type:XDC file:1 line:20 export:INPUT save:INPUT read:READ} [current_design]
set_property -dict { PACKAGE_PIN M1  IOSTANDARD LVCMOS33 } [get_ports { LED }];
